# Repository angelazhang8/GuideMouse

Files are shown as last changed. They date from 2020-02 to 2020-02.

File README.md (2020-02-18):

# Guide Mouse
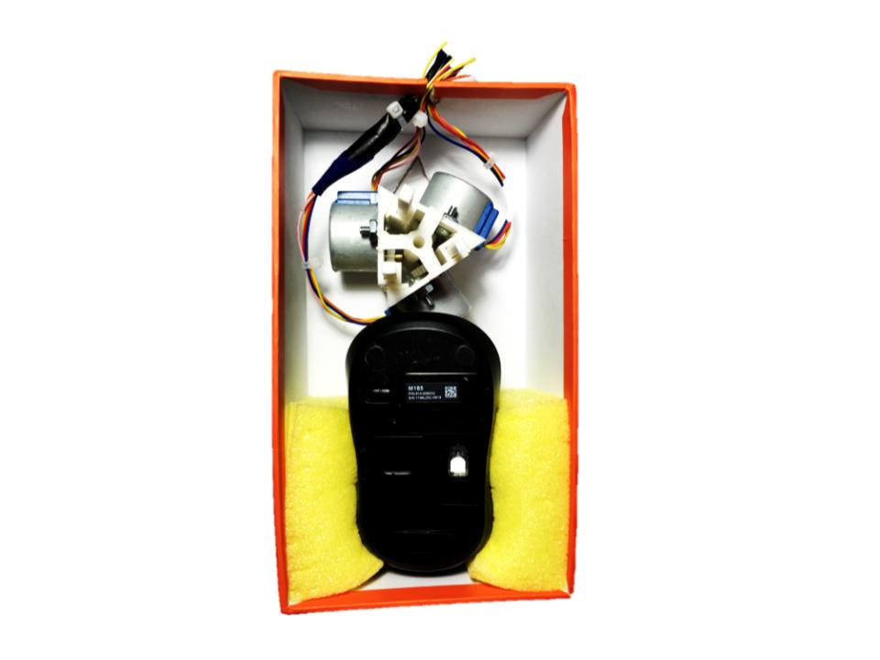
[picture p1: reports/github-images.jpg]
mouse

Guide Mouse allows for the tactile exploration of 3D objects digitally. The program inputs a 3D model while displaying its 2D projection on the screen. Users move the tactile mouse around like a regular computer mouse, which changes the cursor position on the screen. Applicator (the main program running Guide Mouse) identifies the facet of the 3D polyhedron mesh the cursor hovers over on the screen, and it outputs three numerical values to the Arduino board to position a feedback plane by driving three motors that are attached to Guide Mouse.

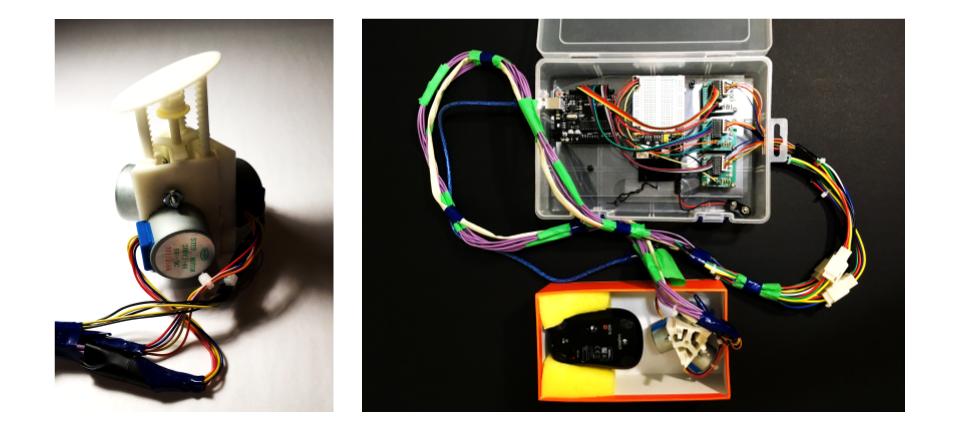
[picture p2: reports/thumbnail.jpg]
thumbnail


## Report & Posters

#### The Applicate Interpolator for a Facet of a 3D Polygon Mesh Given the Abscissa and Ordinate Program

## Program

[Applicolator Report](https://github.com/xxxzhangxxx/GuideMouse/blob/master/reports/applicolatorReport.pdf)

### Poster

[Guide Mouse Poster](https://github.com/xxxzhangxxx/GuideMouse/blob/master/reports/poster.pdf)

## Build Process

[Build Process](https://github.com/xxxzhangxxx/GuideMouse/blob/master/BuildProcess.md)

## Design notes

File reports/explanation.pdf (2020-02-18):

2.
3.

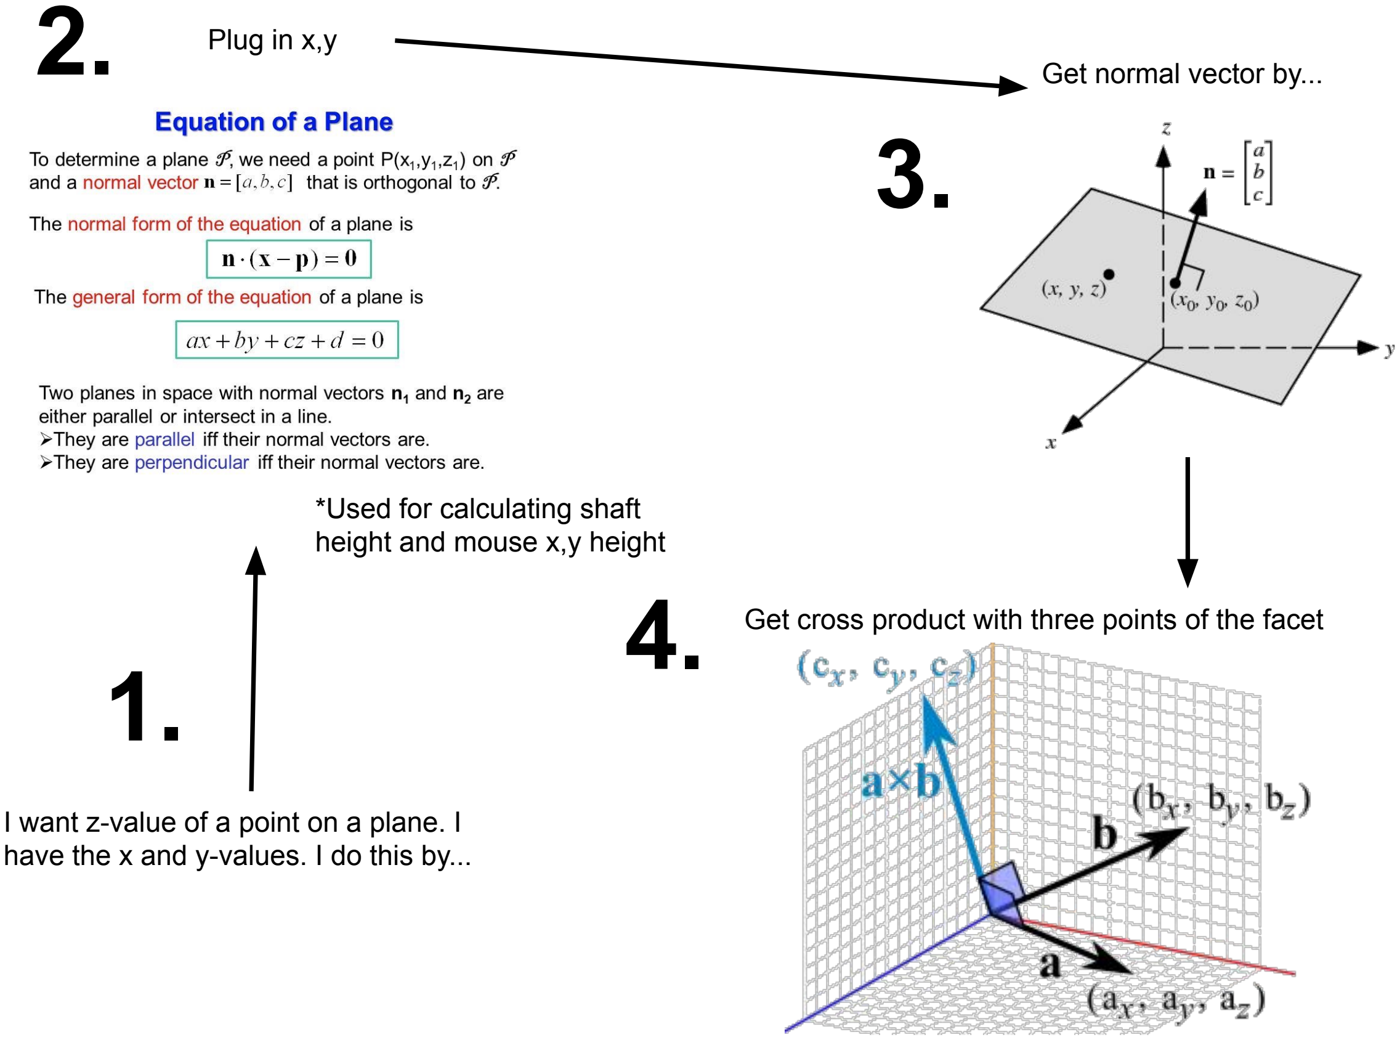
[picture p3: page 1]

Get cross product with three points of the facet

Get normal vector by...

Plug in x,y

I want z-value of a point on a plane. I have the x and y-values. I do this by...

1.

4.

*Used for calculating shaft height and mouse x,y height

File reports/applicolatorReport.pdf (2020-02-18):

# Design Document: Applicolator

# Description of the program

Applicolator displays a 3-dimensional polygon mesh. When the user inputs x,y-values with their cursor position, Applicolator highlights the visible facet that the cursor is currently hovering over and displays its normal vector with a magnitude proportional to the z-value. In order to efficiently locate the visible facet, Applicolator first checks if the x,y-point is in the convex hull of the polyhedron’s projection on the x,y-plane. Second, it builds an interval tree of the smallest enclosing rectangles of facets such that the k facets whose enclosing rectangle the input x,y-values is in can be located in O(k log n) time. Third, for these rectangles, Applicolator uses the ray-casting algorithm to test whether the x,y-values are in the facet. Fourth, Applicolator compares all facets that the x,y-values belong to for the largest z-value. The applicate (z-value) is calculated for the x,y-point by using the normal vector and a point on the facet. The normal vector is calculated by taking the cross product of two vectors obtained from three points on the facet. In this way, the facet that is “on top” can be identified because it will have the greatest z-value. The name Applicolator is derived from The Applicate (z-value) Interpolator for a Facet of a 3-Dimensional Polygon Mesh Given the Abscissa and Ordinate.

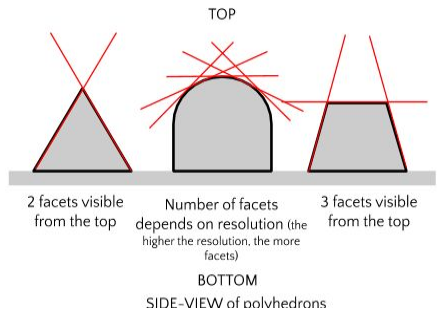
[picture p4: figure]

In computer graphics, one way to define a 3D shape is through a shell/boundary model, which represents the surfaces of the 3D shape like an infinitesimally thin eggshell. Polygon meshes are commonly used, which represents the surfaces of the 3D shape using polygons.

The polygons, also called facets, may be triangles, quadrilaterals, or simple convex polygons. A polygon mesh can be stored in different file formats; Applicolator will be importing .obj files.

A 3D polygon mesh model describes its facets using its own coordinate system, called the object coordinate system. Different .obj files use coordinate systems that represent the length in different units, and the coordinate origin may be far away from the object's center. Applicolator scales and translates the object coordinate system to make the shape fits properly on the computer screen.

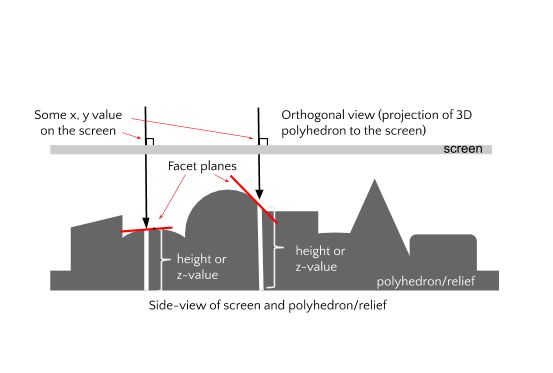
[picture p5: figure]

A polygon mesh will be displayed in an orthogonal view so that x,y-values on the screen match with a scaled version of the polygon mesh. The corresponding applicate (z-value) to the x,y-value can be determined using vector calculations. Applicolator will assume that the z-value is zero at the vertex of the polyhedron containing the smallest z-value and normalize the magnitude of the displayed normal vector to be between zero and one. The ideal polygon mesh for this program is a 3D relief, as reliefs only have one side with 3D detailing.

Essentially, Applicolator is meant to be an interpolator for the z-value given an x,y-value on a plane. In order to achieve this purpose, intermediate calculations are required. These intermediate calculations have, in and of themselves, become useful features.

# Features

Program:
- Identifies and highlights the visible facet that the user’s cursor is hovering over
- Interpolates the z-values, given an x,y-value on the facet
- Display the normal vector of a facet. The magnitude of the vector is first normalized, and then set to the z-value at the x,y-point
- When the user checks off a checkbox, they are able to colour the facets. They can change their colour by turning the colour knobs. In this way, they can create a pretty, coloured 3D shape.

GUI:
- Contain different choices for polyhedrons and reliefs to select from
- Contain different background textures to select from
- Contain an option to check off that allows the user to “colour” the facets for fun
- Contain an RGB colour wheel to allow the user to change the colour of the polyhedron and facets

## Inputs to the program

- An x,y-value that is the cursor’s position on the screen
- GUI inputs
- Checkbox
■ 3D colouring exercise
■ If checked, stop redrawing polyhedron and background
- Dropdowns
■ Texture
■ Polyhedron
- Knobs
■ Change the RGB values for the facet and polyhedron

# Sketch of the User Interface

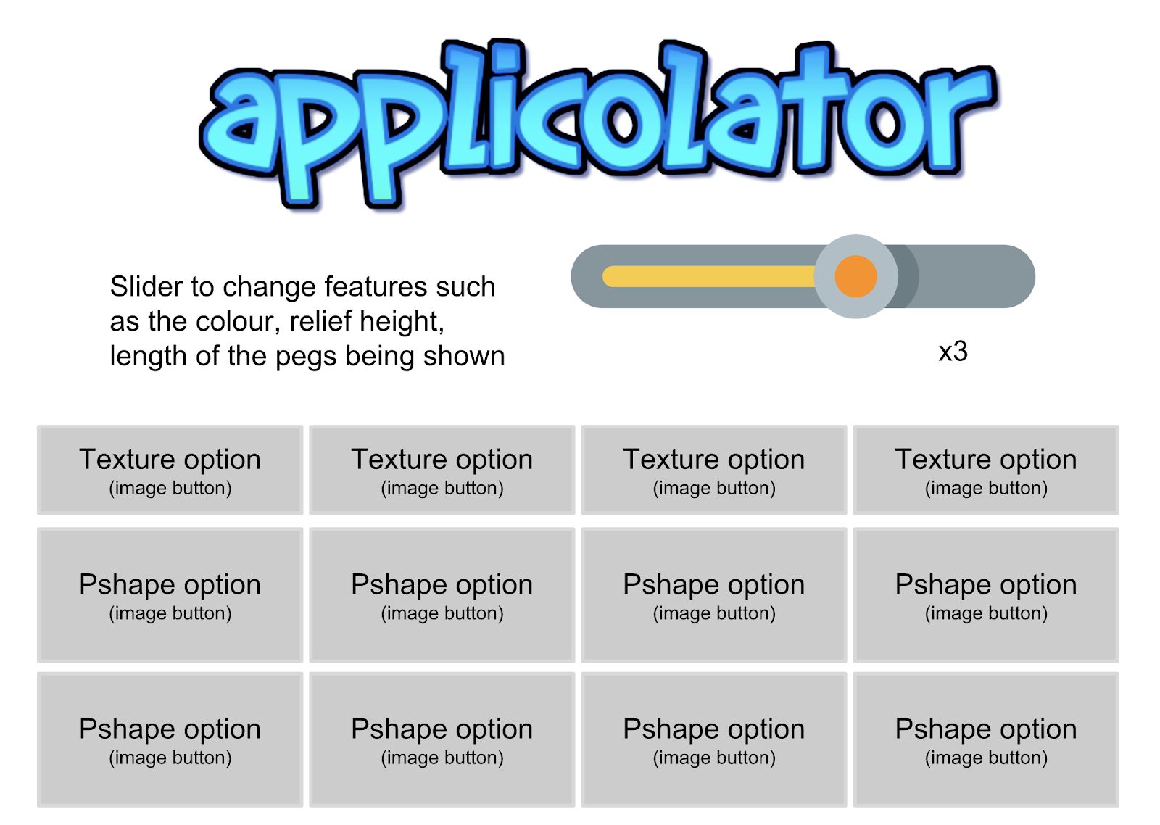
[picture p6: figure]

# Coding structure

## ShapeGeometry2 Class

## General Overview:

Responsible for:
1) Preprocessing the .obj file
- Recursively find all facets, recursively find all vertices
- Finding min/max z-values

2) Storing facets and their smallest enclosing rectangle
- Create an interval tree for the facet’s smallest enclosing rectangle (the top-left-most, top-right-most, bottom-left-most, bottom-right-most points)
- Given an x,y-value, find all the rectangles that it overlaps.

Rules for Interval tree algorithm:
i) The tree is ordered by leftmost x’s value.
ii) | Each node has a maxSubtreeX value which dictates the largest value of x
| in the subtree rooted at that particular node.
iii) | If your point x overlaps with the current node’s shape’s interval, add the
| interval to the result.
iv) | Recur the left child.
v) Recur for the right child if your x value is larger than the right child’s low.
3) Find visible facets
1) Calls convex hull, tests if a point is in the polyhedron’s projection onto the
| x,y-plane
2) Search the interval tree for all the rectangles that enclose the point
3) Test if the point is within the facet using the ray-casting algorithm
4) Calculate the z-value for each point on the facet
5) Compare z-values, the point with the largest z-value is the facet that is
| “on top”
4) Handles vector calculations
- Calculates the normal vector
- Calculate the z-value for an x,y-point

### Fields

PShape convexHull; | Creates shape using points from the convex hull.
float minX, minY, maxX, maxY, maxZ, minZ; | Finds the extreme values from points in convex hull (fewer points to check).
XIntervalTree facetIntervalTree; | Creates an object.

### Methods

ShapeGeometry2() | Empty constructor.
ShapeGeometry2(PShape shape) | Calls the other methods. Initializes fields for the given shape.
void getAllVerticesFromShape(PShape a, HashSet<PVector> v) | Recursive function. Adds all the shape’s vertices to a HashSet to ensure no duplicate values.
private void getAllFacetsFromShape(PShape shape, ArrayList<PShape> allFacets) | Recursive function. Checks if the shape is a facet. If the shape is a facet (the family will have the same constant field value as GEOMETRY), add the facet to the ArrayList. Otherwise, do a recursive call for each child of the shape.

void initializeMinMaxXYZ(HashSet<PVector> vertices) | Initializes field values.
void initializeConvexHull(HashSet <PVector> allVertices) | Creates convex hull from an ArrayList of the polygon’s vertices. Initializes the field value.
float getMinX/getMaxX/getMinY/getMaxY/getMinZ/getMaxZ() / PShape getConvexHull() | Multiple methods that are of the same type. Returns the specified value. Its purpose is to be accessed from other classes.
PShape getVisibleFacet(PVector xy) | First, check if the cursor is within the smallest enclosing rectangle formed by the shape’s four most extreme points. Next, check if the cursor is within the convex hull. Return the final facet with highest z-value or null if the cursor is not on any facet.
boolean isInFacet(PShape shape, PVector xy) | Checks if a point is in a polygon using a ray-casting algorithm https://www.geeksforgeeks.org/how-to-check-if-a-given-point-lies-inside-a-polygon/ (https://www.geeksforgeeks.org/how-to-check-if-a-given-point-lies-inside-a-polygon/)
void setZForXYonPlane(final PVector normal, final PVector position, PVector xy) | Uses vector calculations to find the z-value given the normal vector, position vector and an xy value.
PVector getNormalVector(final PVector a, final PVector b, final PVector c) | Given 3 points on the plane, get the plane’s normal vector.
PVector getNormalVectorAndSetHeight(PShape facet, PVector xy) | Set z-value for cursor position on the screen. Return normal vector. Calls setZForXYonPlane and getNormalVector.

## MotorController Class

## General Overview:

For the future continuation of this project:
- With the eventual goal of making a tactile mouse so that blind people can feel shape geometries of digital objects
- Get the heights for the motors, drives the motors
- Currently, this class does not contribute to the program

### Fields

PVector p1, p2, p3; | Positions of each motor relative to the cursor.
PVector mouseXY; | Where the cursor is.

### Methods

MotorController(PVector p1, PVector p2, PVector p3) | Constructor.
void moveMotor(float h, PVector normal ) | Calls setZForXYonPlane.
void setZForXYonPlane(final PVector normal, PVector xy) | Sets z-values for a motor.
float getMotorHeight(int motor) | Return motor height.

## DirtyWork Class

## General Overview:

- Draw relief, highlight the facet, and draw the normal vector that uses object coordinates on the screen
- Convert the mouseXY position from the screen coordinates to object coordinate
- When the cursor changes position, the process above is repeated and Applicolator then redraws the GUI

### Fields

PShape shape; | Relief or polyhedron.
ShapeGeometry2 sg; | Geometry data of the relief.
float scaleFactor; | Object coordinate to screen coordinate scale multiplier.
MotorController motorController; | Motor data. Not in use in the program
PVector mouseXY; | Current cursor position.
Float normalVectorMagnitudeFactor; | Normal vector magnitude multiplier
float motorHeightFactor | Not in use in the program.

### Methods

void printStates() | Troubleshooting.
void initialize(PShape shape) | Initializes the field scaleFactor. The polyhedron will be scaled on the screen appropriately. Initializes shape geometry.
void mouseMoves() | Call other methods depending on the cursor position.
void drawRelief() | Colours and draws the polyhedron
void highlightFacet(PShape facet) | Colour the facet the cursor is on.
void drawNormalVector(PVector normal, PVector mouseXY) | Draws the normal vector for the facet.
void drawWithObjectCoordinate(PShape shape) | Draw the shape that uses object coordinates on the screen.
void screenToObjectCoordinate(PVector xy) | Change screen space to object space for the cursor.

## Convex Hull Class

General overview:
Implement the Graham Scan algorithm to find the convex hull of a set of vertices.

### Fields (none)

### Methods

ConvexHull() | Empty constructor.
ArrayList<PVector> getConvexHull(HashSet<PVector> v) | Return the convex hull of the provided set of vertices, which must be distinct in terms of x and y.
int indexOfBottomestPoint(ArrayList<PVector> points) | Returns the index of the point with the smallest 'y' value
swap(ArrayList<PVector> points, int i, int j) | Swap the points at the two indexes in the array
float counterClockWise (PVector o, PVector a, PVector b) | Position vectors 'a' and 'b' Calculate the cross product of vectors 'a' and 'b' If ccw > 0, then counterclockwise, or < 180 degrees If ccw < 0, then clockwise, or > 180 degrees If ccw = 0, then collinear
float calculateDistance(PVector a, PVector b) | Return the distance between the two points.
ArrayList<PVector> grahamScan(ArrayList<PVector> points) | Graham Scan algorithm: https://en.wikipedia.org/wiki/Graham_scan

| Take in an array of points sorted by polar angles The point at index 0 is the origin Returns the convex hull, the points are in the same order as in the input array
ArrayList<PVector> sortByPolarAngle(ArrayList<PVector> points) | Take the ArrayList 'points' and sort them based on: 1. The point at index 0 is the origin 2. Find position vectors for all points using the newly established origin 3. Sort points based on their vectors' polar angles
ArrayList<PVector> mergeSort(PVector o, ArrayList<PVector> v, int start, int end) | Sorts the vectors in the specified range by polar angle. The vectors are from the point 'o' to the points in the ArrayList v. Both start and end are inclusive.
ArrayList<PVector> merge(PVector o, ArrayList<PVector> a, ArrayList<PVector> b ) | Merge the two arrayLists.

## XIntervalTree Class

General overview:
Interval tree of rectangles. The key is the x1 of the rectangles. The interval refers to [x1, x2]. A node may contain multiple shapes with the same x1; these shapes are stored in the list swer. The k number of smallest-enclosing rectangles that a point (x,y-value from the cursor) is within can be found in O(k log n) time where n is the number of nodes.

### Fields

XIntervalTreeNode root; | Root of the interval tree.
int numNodes, numRectangles; | The number of nodes in tree and number of enclosing rectangles. For debugging purposes

### Methods

ArrayList<PVector> getConvexHull(HashSet<PVector> v) | Return the convex hull of the provided set of vertices, which must be distinct in terms of x and y.
XIntervalTreeNode buildTree(ArrayList<ShapeWithEnclosingRectangle> swer, int begin, int end) | Build the interval tree using the elements of swer in the range of begin to end. Begin is inclusive, end is exclusive. Swer has been sorted by x1. Recursively build the tree. Get the middle node every level. If you left and right and the values for x1 are the same, add it to the current node. Recursively build left and right side of the tree. Update maxsSubtreeX.
ArrayList<ShapeWithEnclosingRectangle> getAllRectanglesOverlapXY(float x, float y) | Return all rectangles that overlap with the provided x and y values.
void getAllRectanglesOverlapXY(XIntervalTreeNode node, float x, float y, ArrayList<ShapeWithEnclosingRectangle> result) | Add rectangles that overlap with the provided x and y to results. Recursively gets called for each side of the tree.
void printTree(boolean verbose) | For testing purposes.
void printTree(String indent, XIntervalTreeNode root,
boolean verbose)

## ShapeWithEnclosingRectangle Class

### Fields

PShape shape; | Facet in question.
float x1, x2, y1, y2; | Coordinates of the smallest enclosing rectangle

### Methods

ShapeWithEnclosingRectangle(PShape shape) | Constructor.
boolean overlapX(float x) | Whether the given x is within x-range of the smallest enclosing rectangle
boolean overlapY(float y) | Whether the given y is within y-range of the smallest enclosing rectangle
public int compareTo(ShapeWithEnclosingRectangle other) | Used by Collections.sort to sort objects of this class by x1
void printStates() | For troubleshooting.

## XIntervalTreeNode Class

General Overview:
A node on the interval tree. The key is the x1 of the rectangle. The interval refers to [x1, x2]. A node may contain multiple shapes with the same x1; these shapes are stored in the list swer.

### Fields

XIntervalTreeNode left, right; | Left and right child node of the current node.
ArrayList<ShapeWithEnclosingRect angle> swer; | All enclosing rectangles with the same x1.
float maxSubtreeX; | Max value of x2 in all nodes under the current node.
float x1; | The leftmost x-value, same for all enclosing rectangles

### Methods

XIntervalTreeNode(ShapeWithEnclosingRectangle r) | Constructor.
void add(ShapeWithEnclosingRectangle r) | Add the rectangle of the same x1 to the node.
void printStates() | Troubleshooting purposes.

# Restrictions and Requirements

The requirement for the ideal 3D polyhedron for Applicolator:
- From a top view, all facets of interest must be visible
- .obj files for polygon meshes cannot exceed the size that Processing allows with minimal lagging
- If file sizes are too large, reduce file size by reducing the number of facets in the polygon mesh using a tool such as Blender

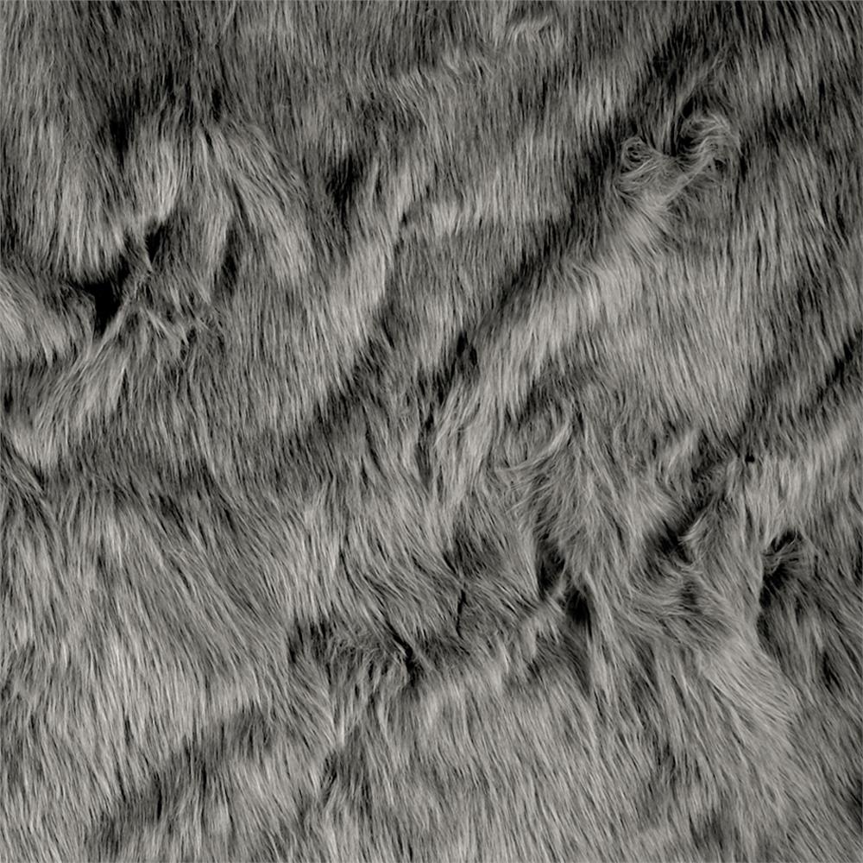
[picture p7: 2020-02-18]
Processing-code/t-fur.jpg

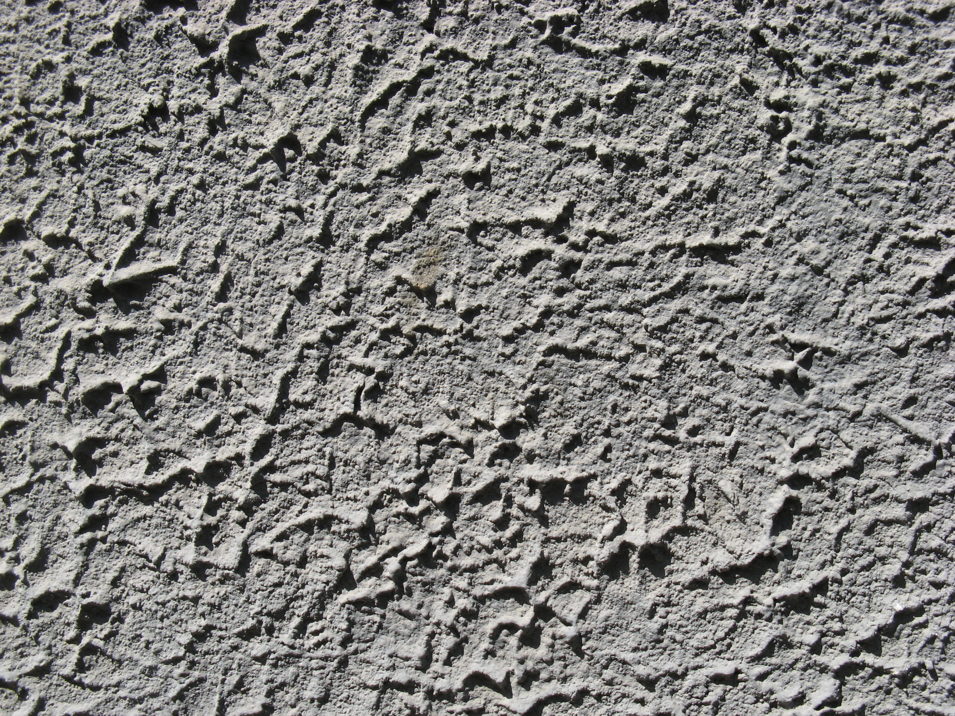
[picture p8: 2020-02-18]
Processing-code/t-plaster.jpg

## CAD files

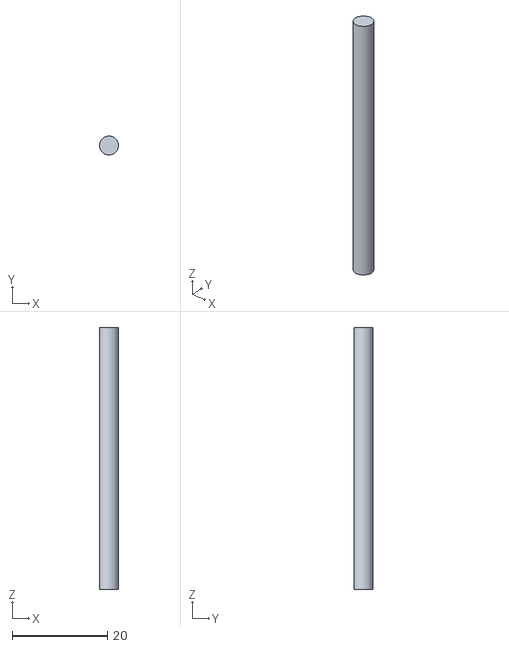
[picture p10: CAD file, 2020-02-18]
AutoCAD-models/STL files/middle-peg.stl
4.00 x 4.00 x 55.0

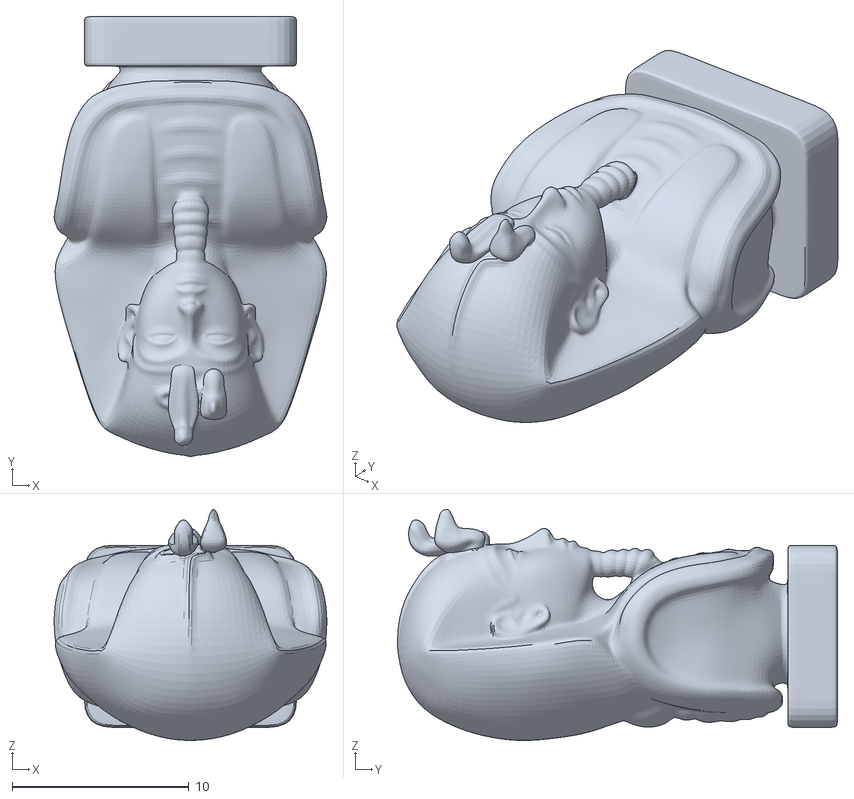
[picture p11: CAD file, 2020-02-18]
Processing-code/s-pharaoh.obj
15.4 x 24.9 x 13.1

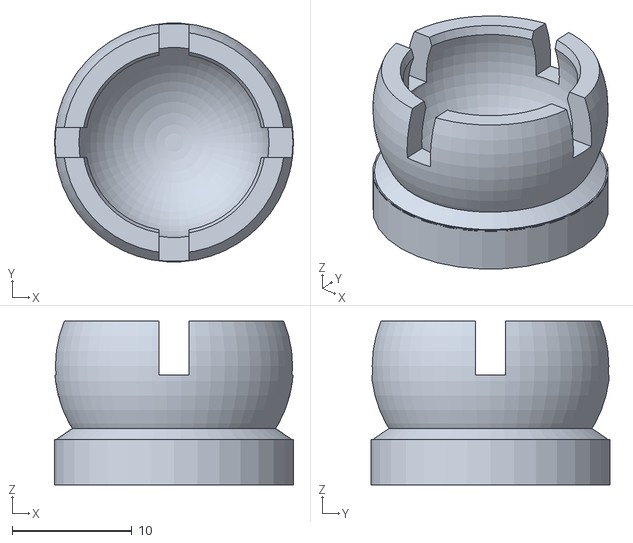
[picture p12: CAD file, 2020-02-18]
AutoCAD-models/STL files/socket_(resize-to-0.51-to-3D-print).stl
20.0 x 20.0 x 13.7

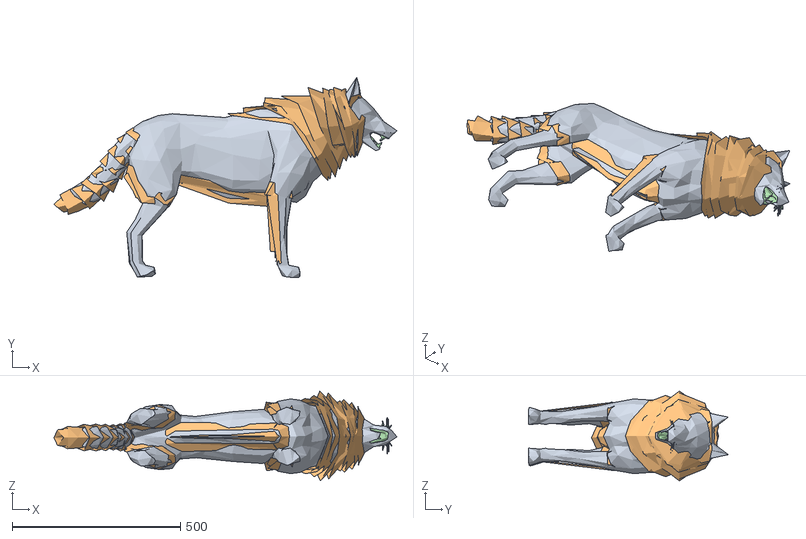
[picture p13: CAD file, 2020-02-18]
Processing-code/s-wolf.obj
1018.1 x 593.0 x 266.8
grp1
grp1 grp1_2
grp1 grp3
grp1 grp2

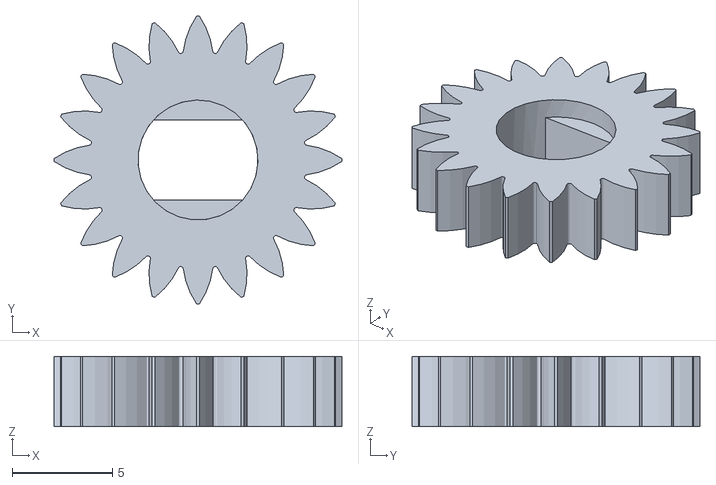
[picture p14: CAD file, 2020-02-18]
AutoCAD-models/STL files/gear.stl
14.4 x 14.4 x 3.50

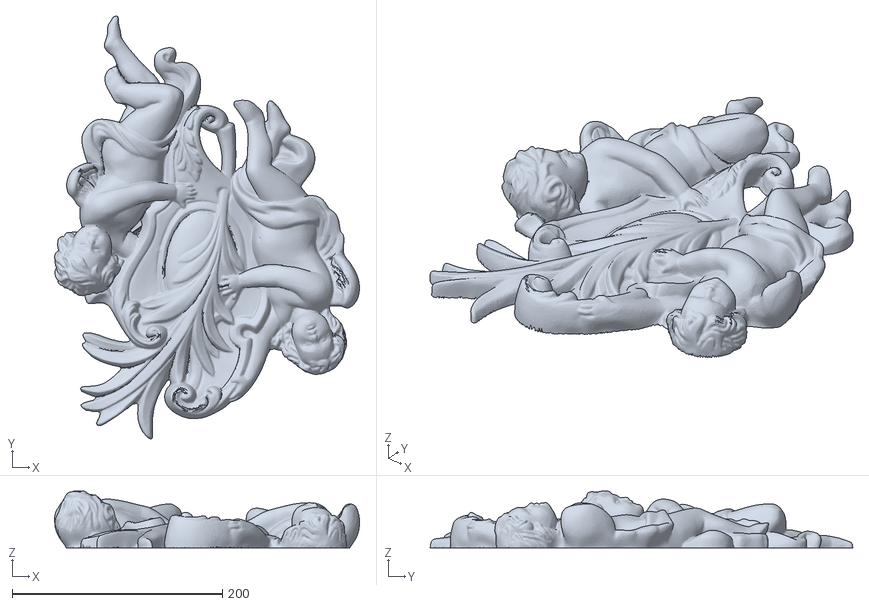
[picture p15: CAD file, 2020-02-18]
Processing-code/s-relief-angel.obj
290.4 x 402.7 x 54.2

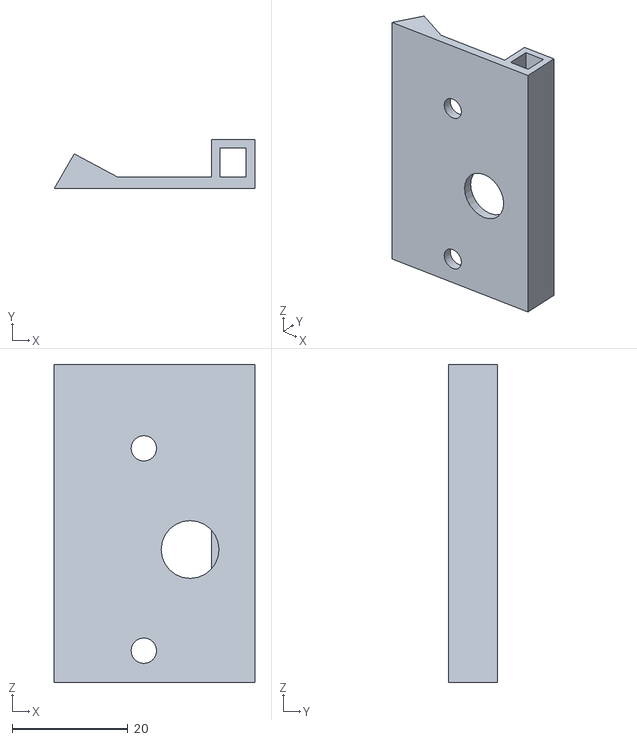
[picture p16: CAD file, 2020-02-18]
AutoCAD-models/STL files/motor-holder.stl
34.7 x 8.50 x 55.0

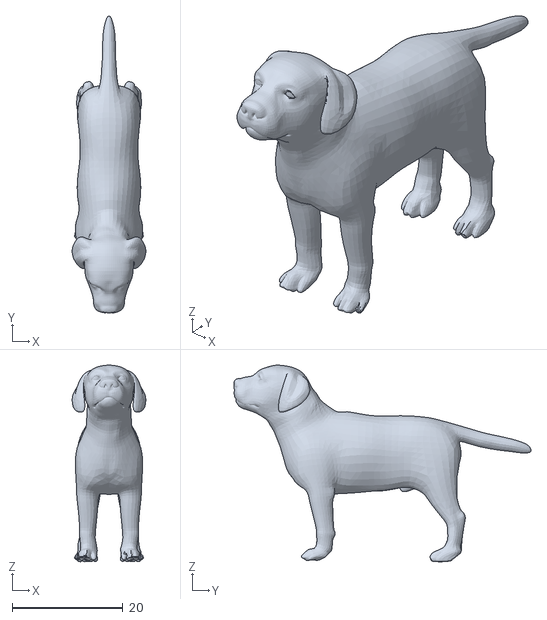
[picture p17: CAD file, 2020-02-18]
Processing-code/s-dog.obj
13.3 x 53.6 x 35.5

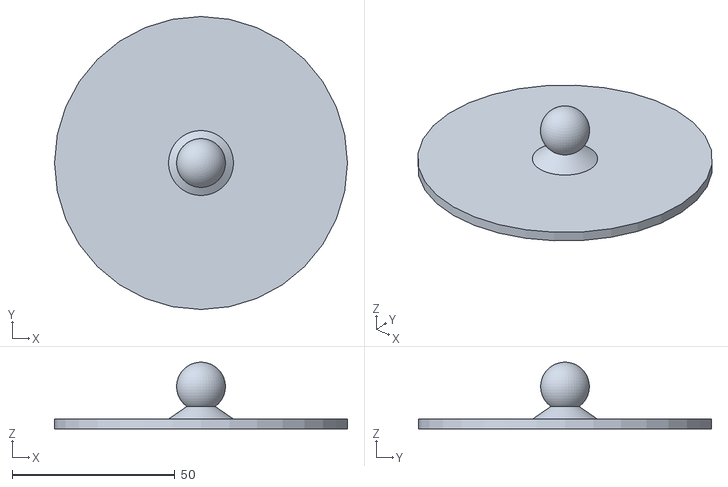
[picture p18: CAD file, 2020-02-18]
AutoCAD-models/STL files/disk_(resize-0.5-to-3D-print).stl
90.0 x 90.0 x 20.5

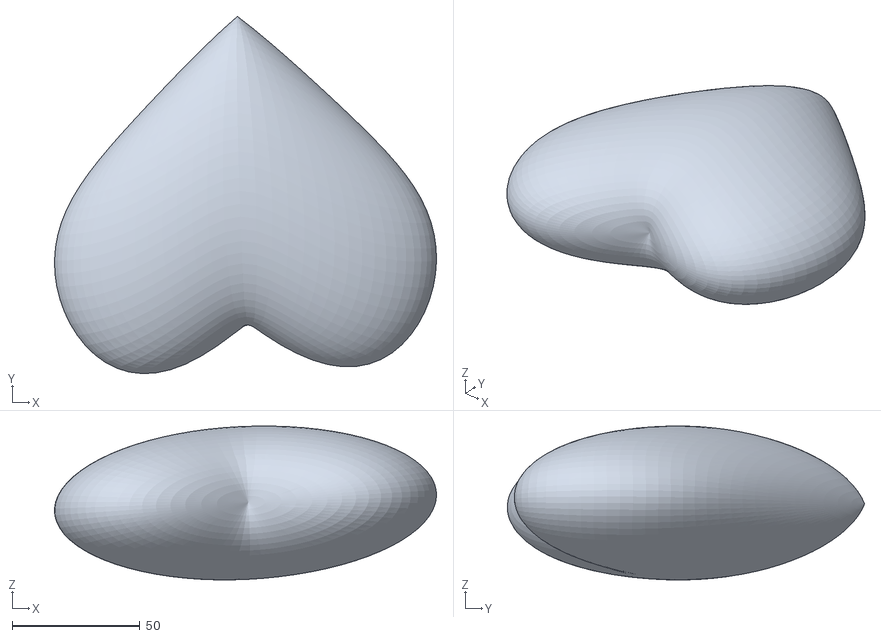
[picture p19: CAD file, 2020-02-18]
Processing-code/s-heart.obj
149.8 x 140.1 x 60.3

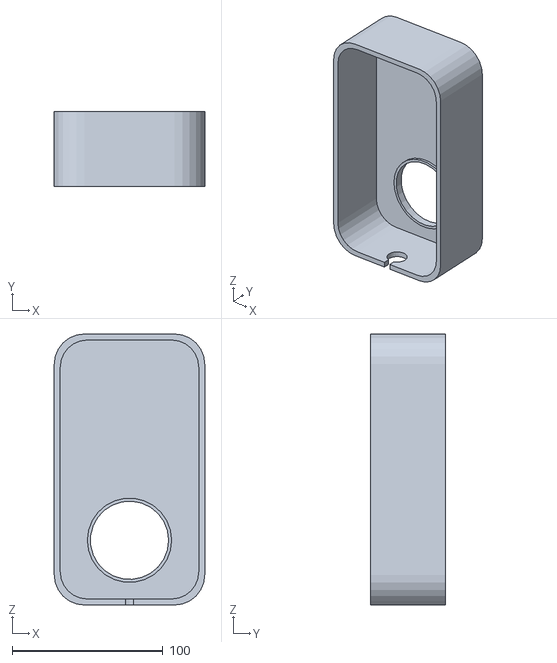
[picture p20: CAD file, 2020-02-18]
AutoCAD-models/STL files/mouse-shell.stl
100.0 x 50.0 x 180.0

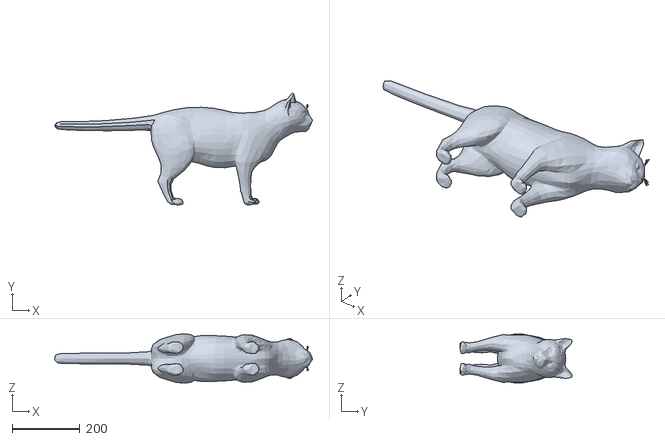
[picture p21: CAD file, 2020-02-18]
Processing-code/s-cat.obj
762.0 x 331.2 x 144.4

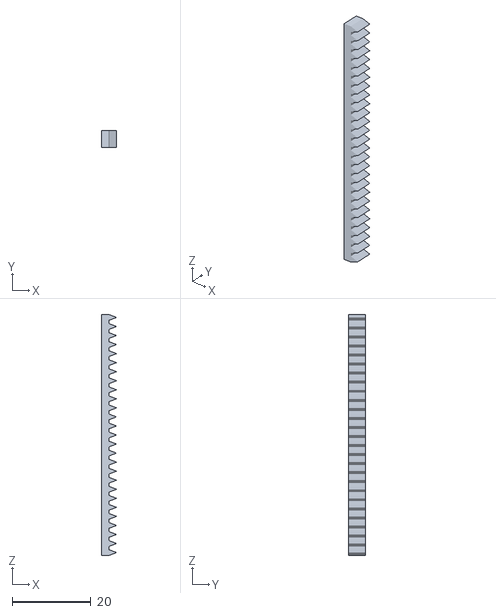
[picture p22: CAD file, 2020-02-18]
AutoCAD-models/STL files/rack.stl
3.88 x 4.40 x 61.3

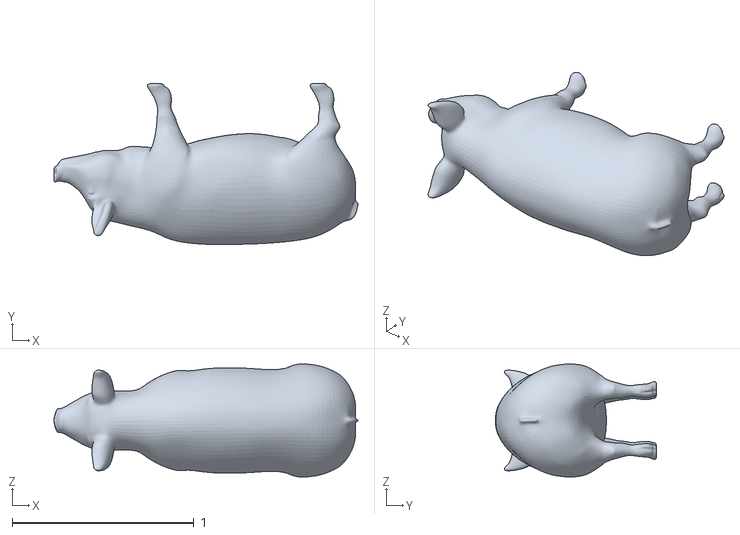
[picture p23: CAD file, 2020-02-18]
Processing-code/s-pig.obj
1.67 x 0.886 x 0.621

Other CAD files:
AutoCAD-models/DWG files/moto-holder.dwg
AutoCAD-models/STL files/middle-peg-holder.stl
Processing-code/s-rat.obj
Processing-code/s-tree.obj
AutoCAD-models/DWG files/disk.blend
AutoCAD-models/DWG files/gear.dwg
AutoCAD-models/DWG files/middlepeg.dwg
AutoCAD-models/DWG files/mouse-shell.dwg
AutoCAD-models/DWG files/rack.dwg
AutoCAD-models/DWG files/socket.blend
Processing-code/s-angel.obj
Processing-code/s-cow.obj
Processing-code/s-deer.obj
Processing-code/s-goat.obj

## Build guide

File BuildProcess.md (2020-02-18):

### Inspiration 
I was inspired to create Guide Mouse after trying out the Phantom Omni at SHAD Western '17. 
Computers have auditory feedback (speakers) and visual feedback (screen) but no tactile feedback. Touch feedback is a large component of our day-to-day lives, yet a nonexistment form of interaction with our desktop computers. I wanted to build this project because Guide Mouse is a product I would like to use.

### Ideation
Going into this project, I had no idea what Guide Mouse was going to look like. So I made rough sketches and then migrated to making paper and foam models to flesh out my idea.

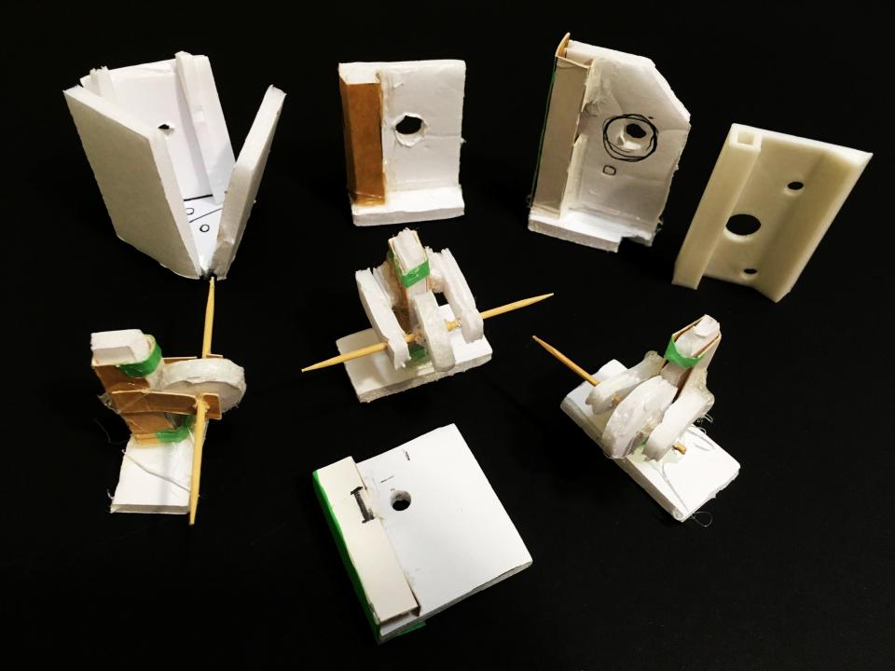
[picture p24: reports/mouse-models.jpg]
mouse-models


### Applicolator
To obtain the normal vector for each facet plane of the polyhedron mesh, I calculated the cross product of two vectors making up the facet plane.
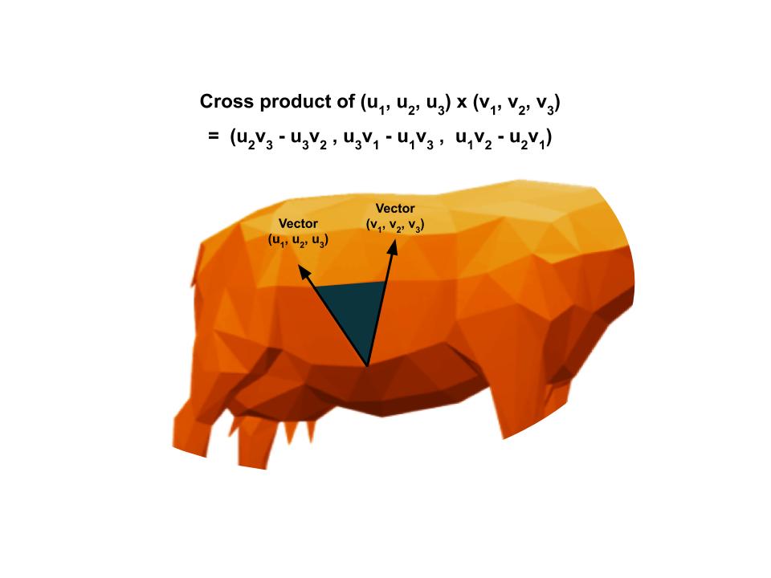
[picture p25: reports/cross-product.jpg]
cross-product

### CAD Modelling
After Guide Mouse had become a skeleton of an idea, I proceded to make CAD models for the parts I needed to 3D-print. Ball/socket model [not pictured] was mixed in Blender from Ball/Joint in Thingiverse.

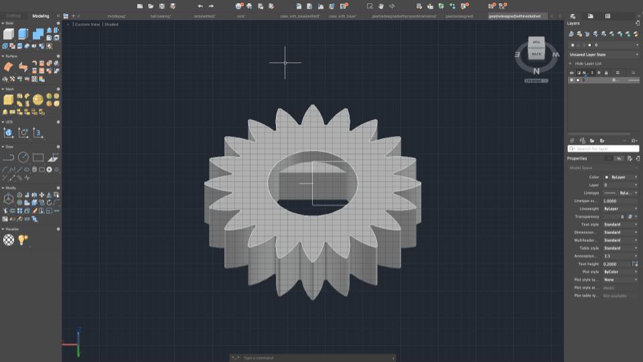
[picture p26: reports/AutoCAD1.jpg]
AutoCAD1

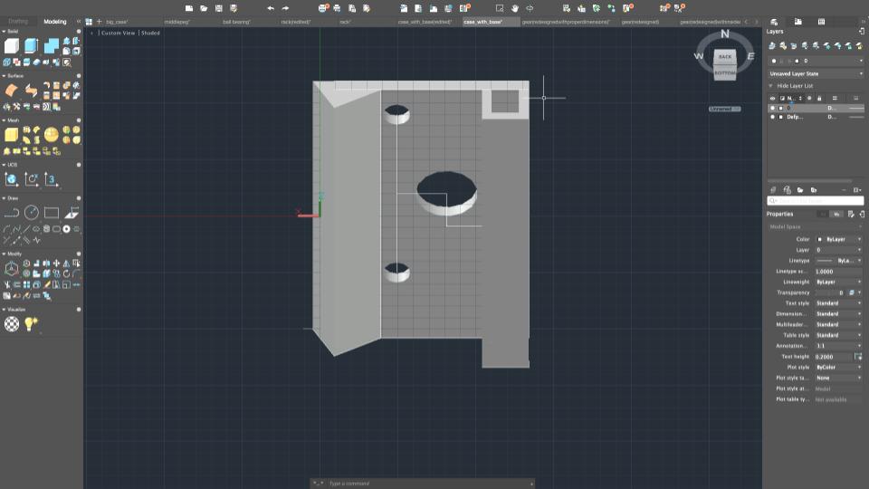
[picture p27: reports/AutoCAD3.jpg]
AutoCAD3

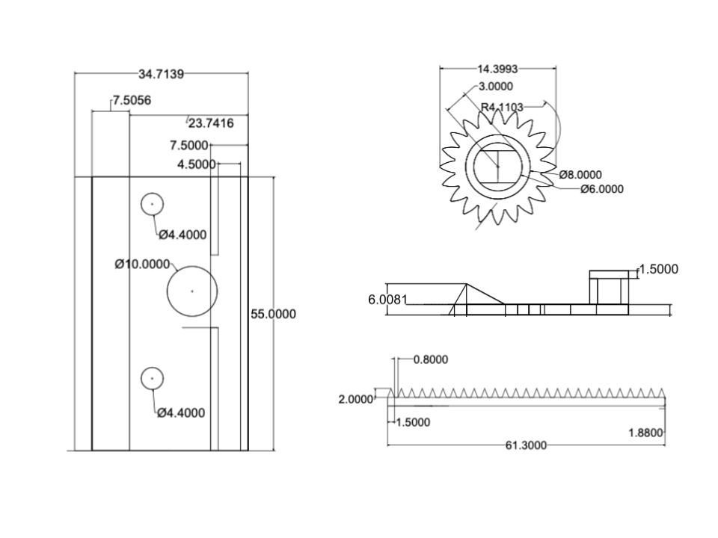
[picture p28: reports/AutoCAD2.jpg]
AutoCAD2

### 3D-Printing
My high school had the Cubicon 3D printer which I used to print my parts.

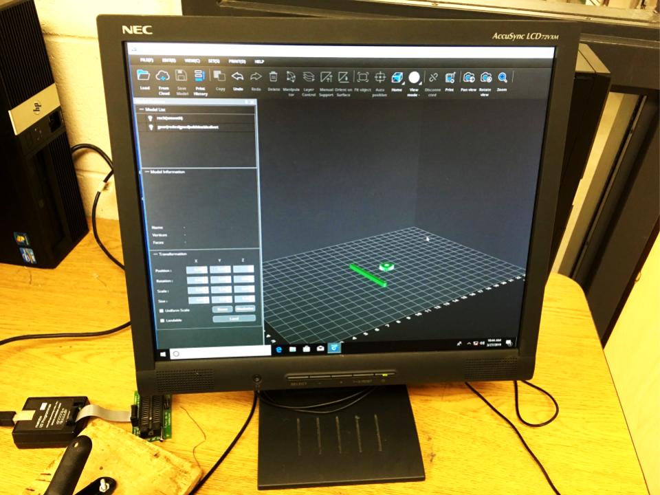
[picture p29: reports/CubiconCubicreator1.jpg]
CubiconCubicreator1

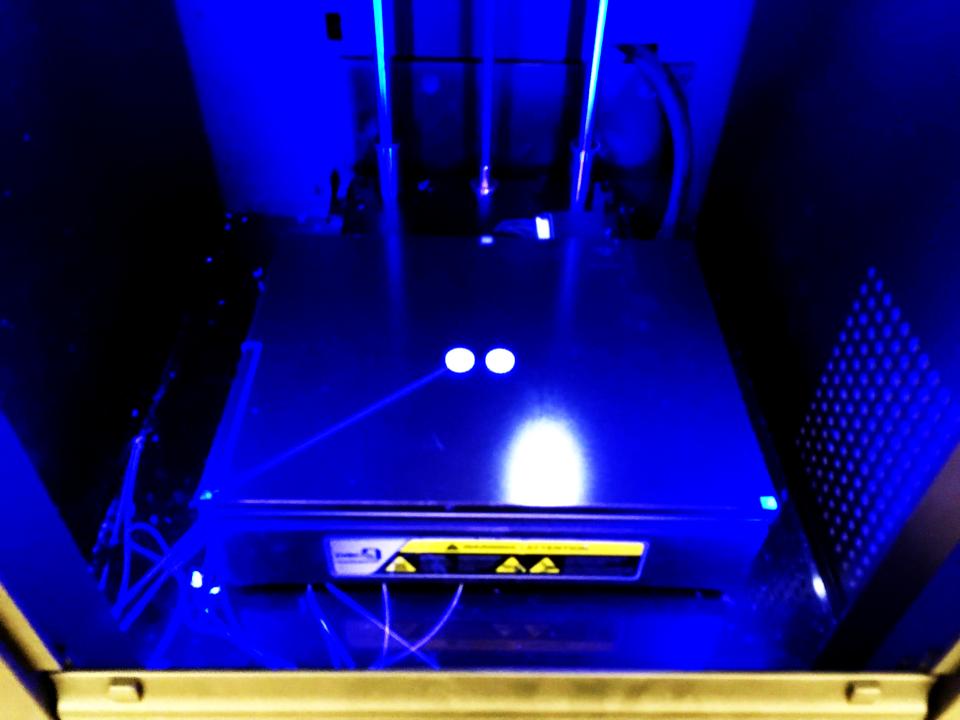
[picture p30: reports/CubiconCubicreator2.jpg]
CubiconCubicreator2


### Soldering (16 hours)
My impromptu work station in the basement; my setup was a ping pong table covered with a picnic blanket. I soldered a computer connector from the motor chip to the motors so that the motors have longer connecting wires and can be easily separated from the motor chip.

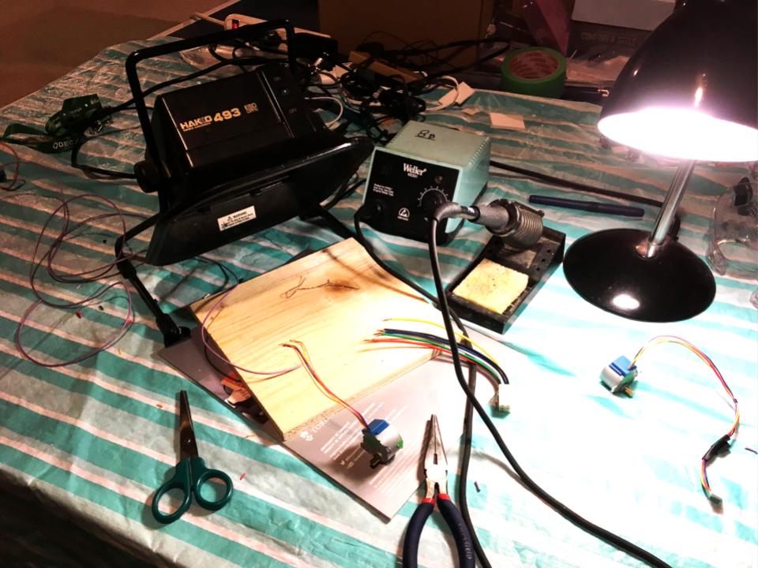
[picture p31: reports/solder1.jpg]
solder1

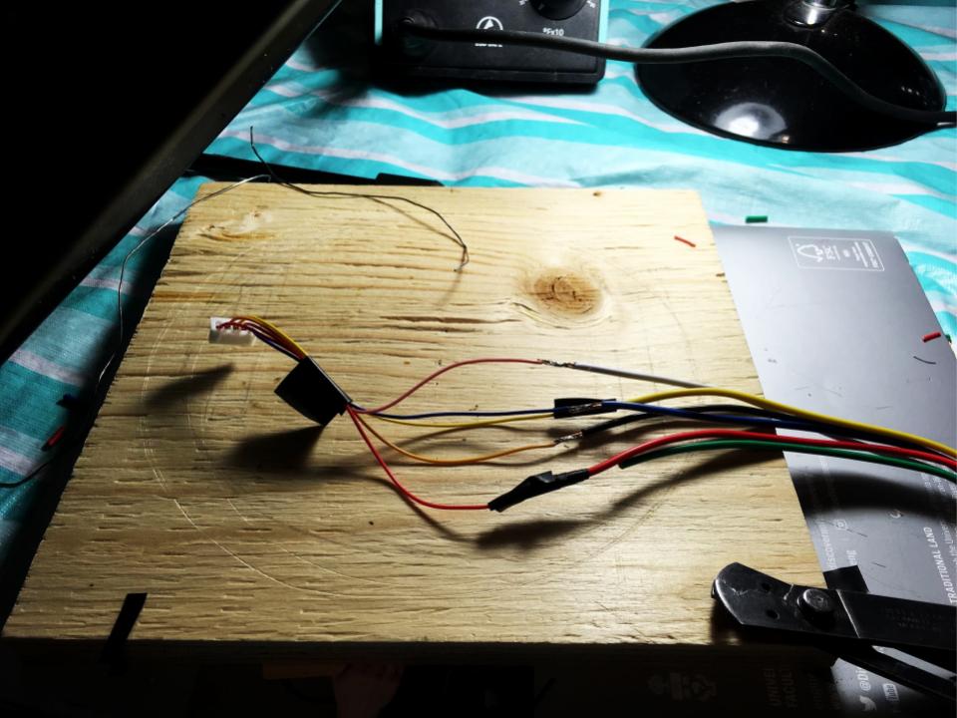
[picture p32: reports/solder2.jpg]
solder2


Wires were stripped, twisted, soldered, and taped. Soldering iron, fan, pliers/cutters were generously lent by Mr. Webb.

### Putting it together
After months of work, it's finally time to fit all the pieces together!

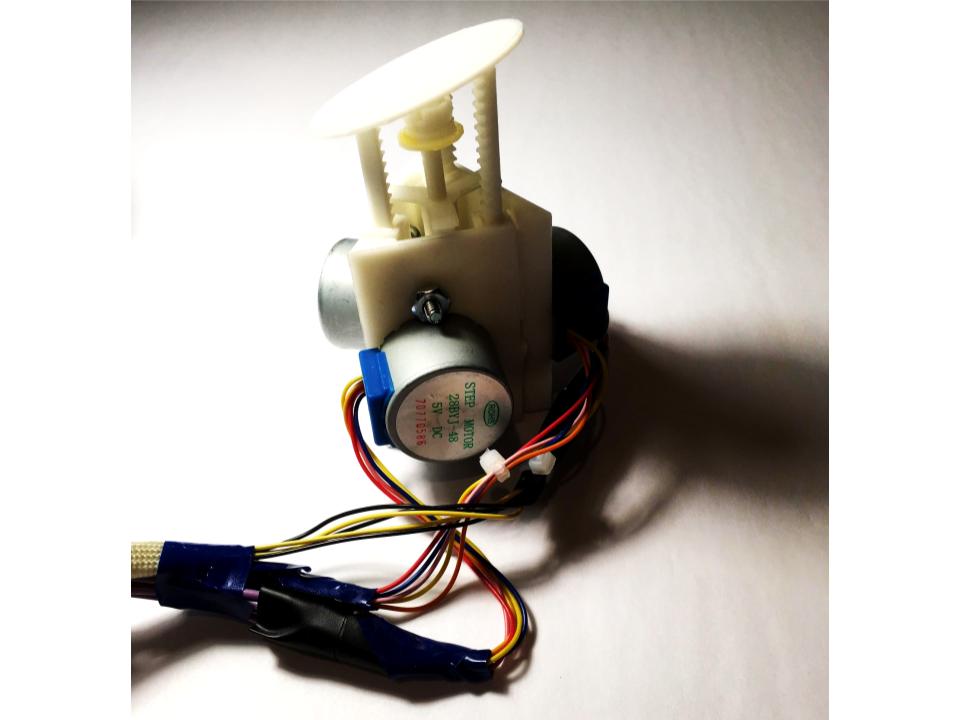
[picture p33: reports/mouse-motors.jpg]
mouse-motors

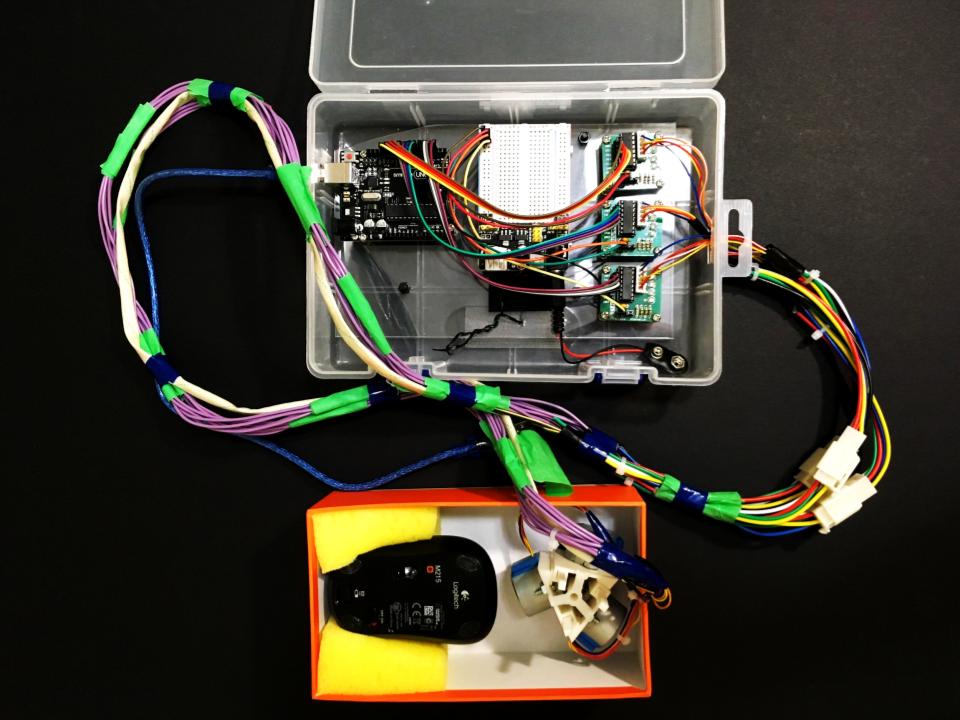
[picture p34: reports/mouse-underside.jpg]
mouse-underside


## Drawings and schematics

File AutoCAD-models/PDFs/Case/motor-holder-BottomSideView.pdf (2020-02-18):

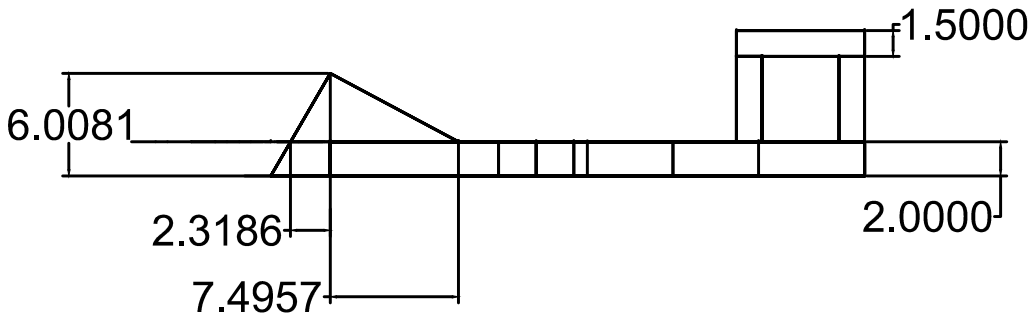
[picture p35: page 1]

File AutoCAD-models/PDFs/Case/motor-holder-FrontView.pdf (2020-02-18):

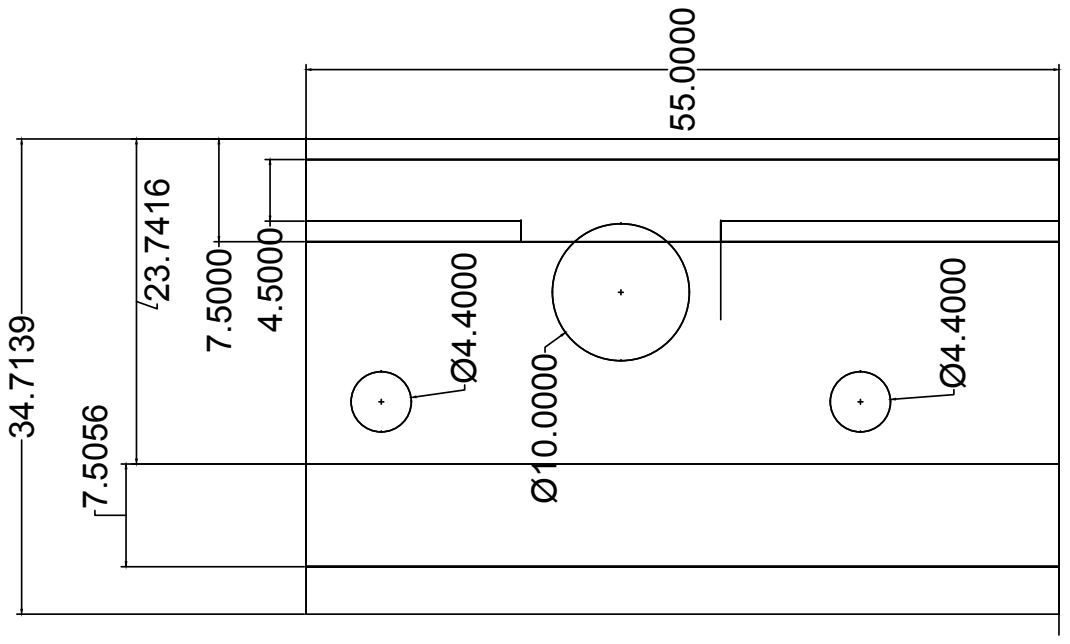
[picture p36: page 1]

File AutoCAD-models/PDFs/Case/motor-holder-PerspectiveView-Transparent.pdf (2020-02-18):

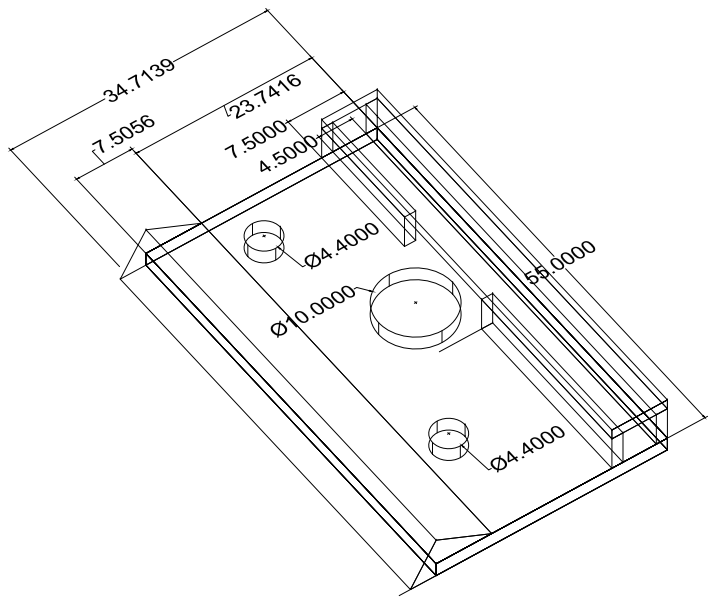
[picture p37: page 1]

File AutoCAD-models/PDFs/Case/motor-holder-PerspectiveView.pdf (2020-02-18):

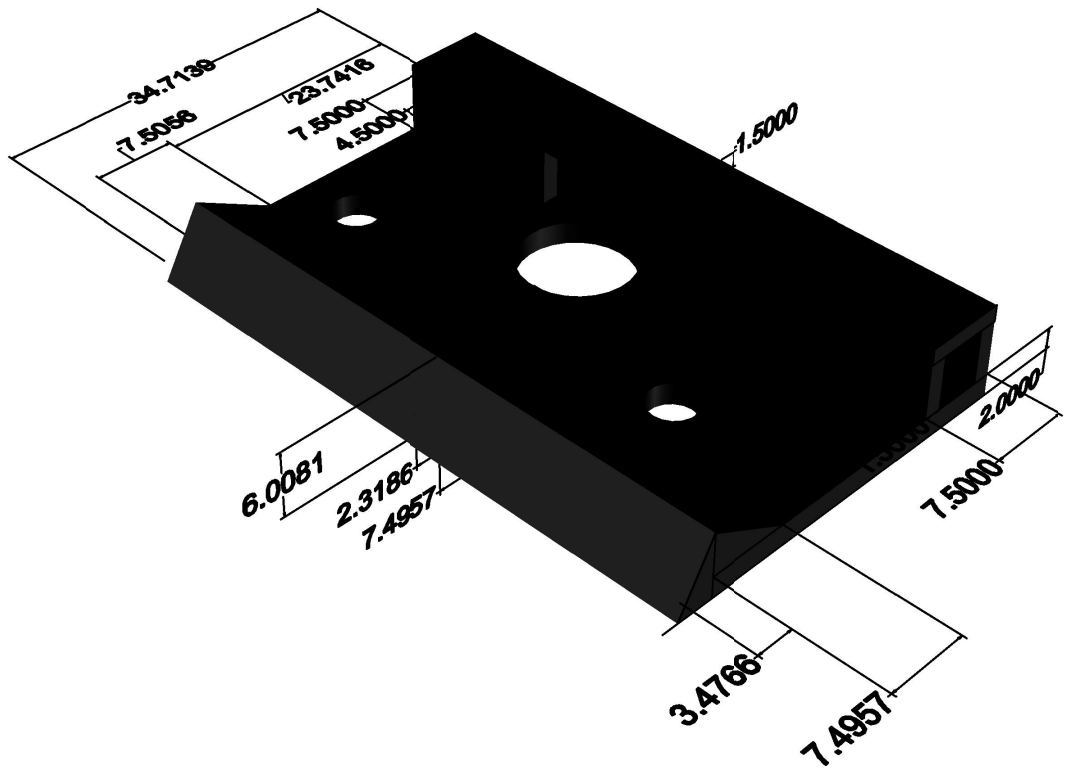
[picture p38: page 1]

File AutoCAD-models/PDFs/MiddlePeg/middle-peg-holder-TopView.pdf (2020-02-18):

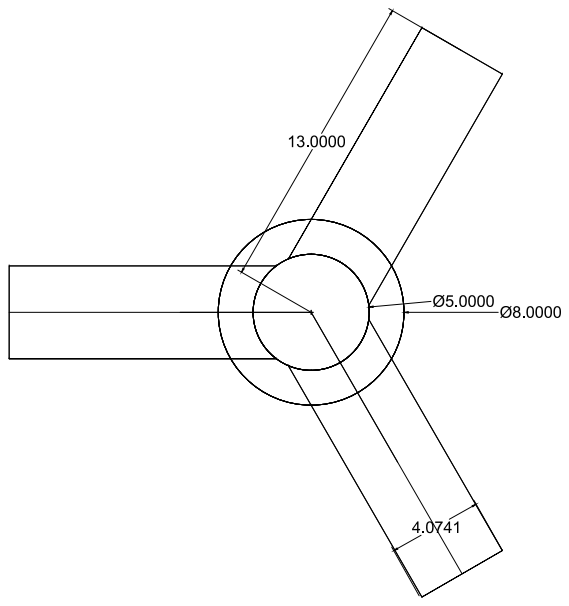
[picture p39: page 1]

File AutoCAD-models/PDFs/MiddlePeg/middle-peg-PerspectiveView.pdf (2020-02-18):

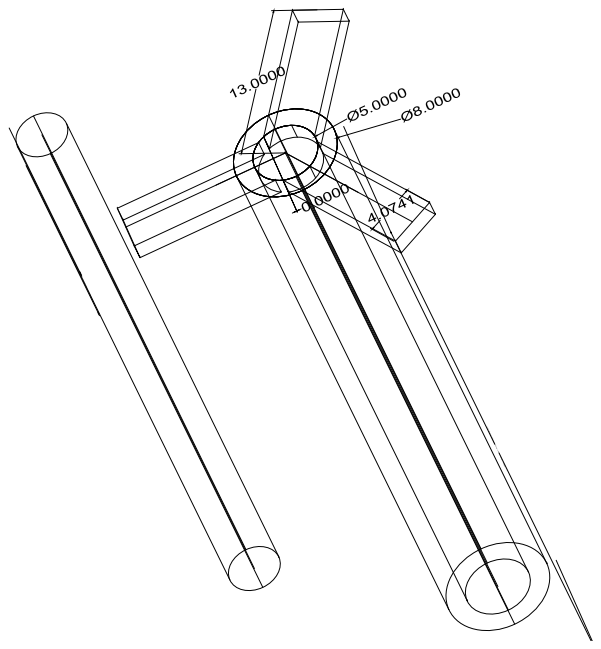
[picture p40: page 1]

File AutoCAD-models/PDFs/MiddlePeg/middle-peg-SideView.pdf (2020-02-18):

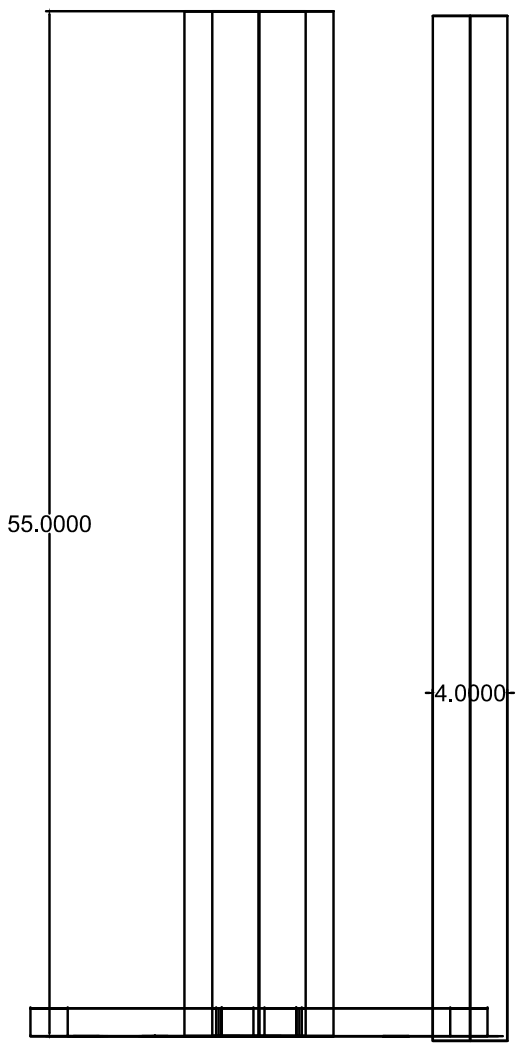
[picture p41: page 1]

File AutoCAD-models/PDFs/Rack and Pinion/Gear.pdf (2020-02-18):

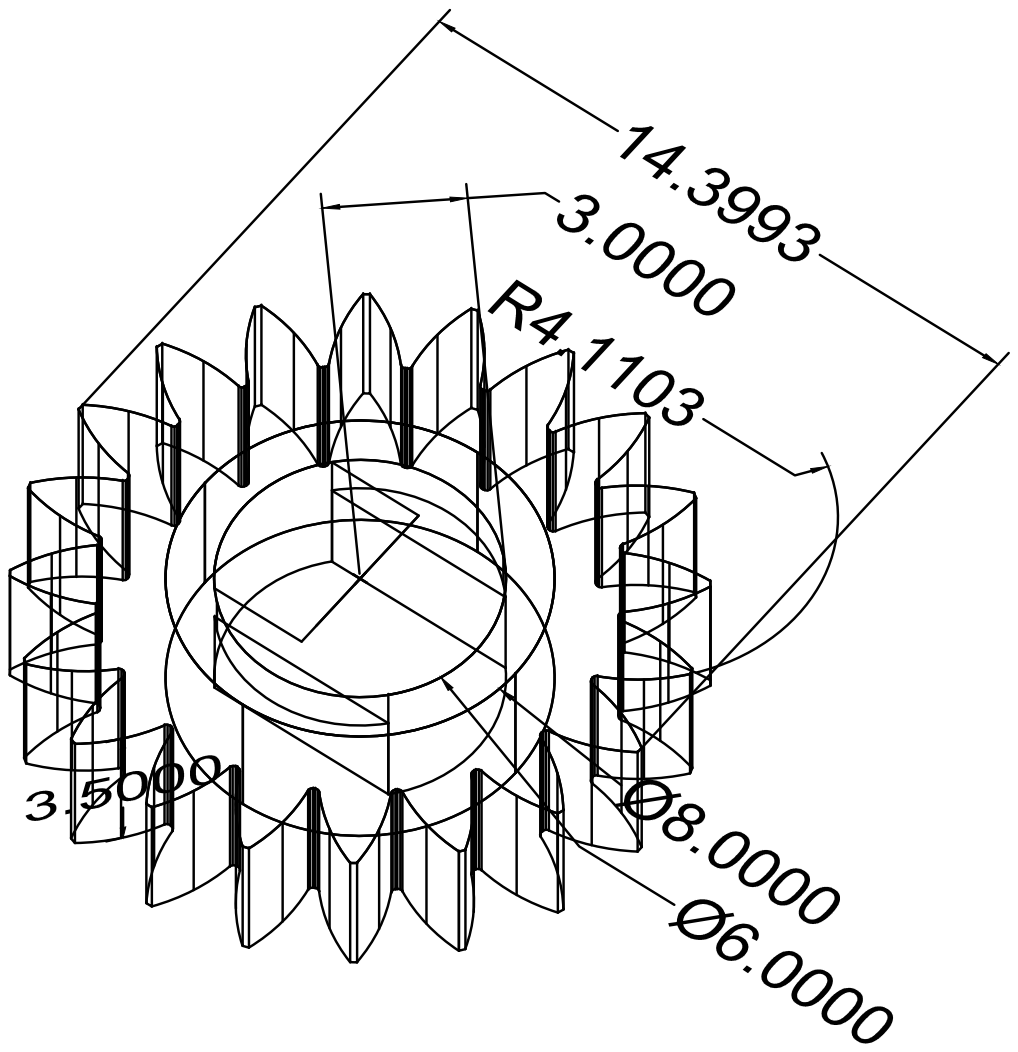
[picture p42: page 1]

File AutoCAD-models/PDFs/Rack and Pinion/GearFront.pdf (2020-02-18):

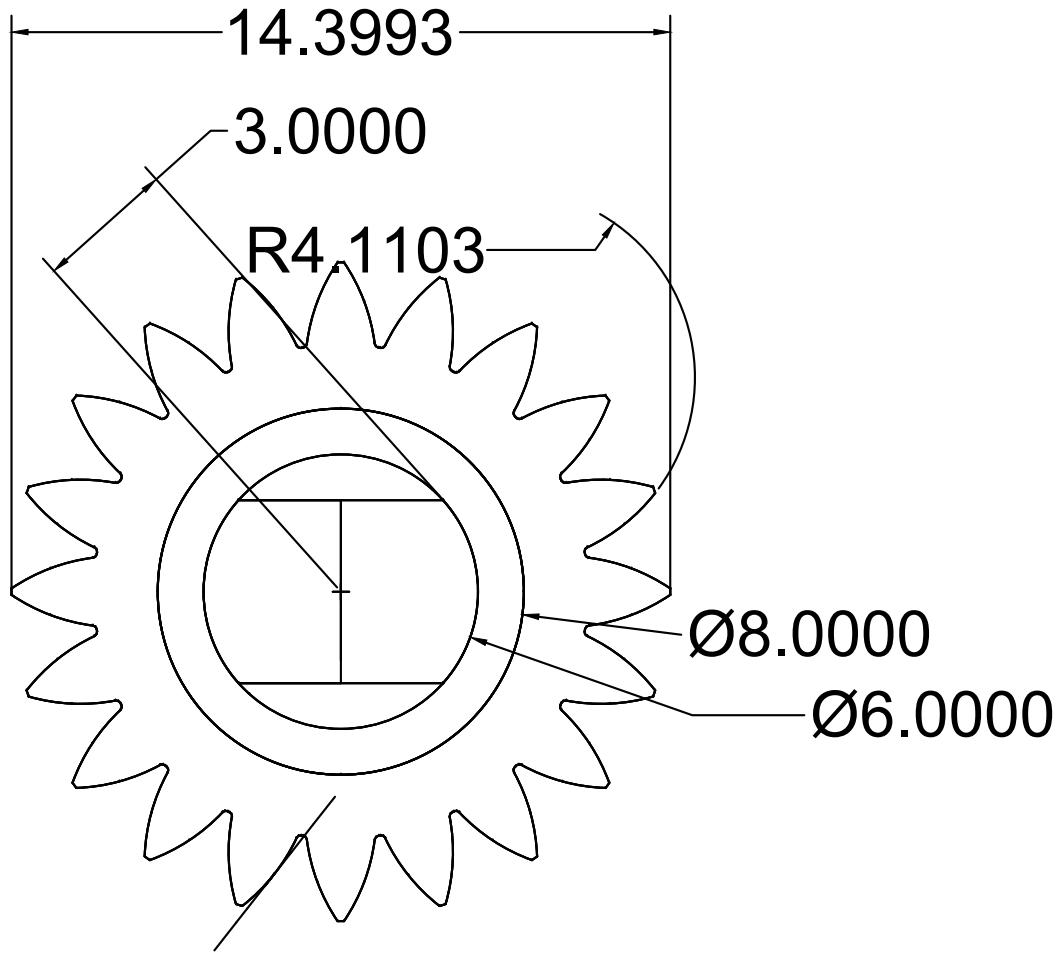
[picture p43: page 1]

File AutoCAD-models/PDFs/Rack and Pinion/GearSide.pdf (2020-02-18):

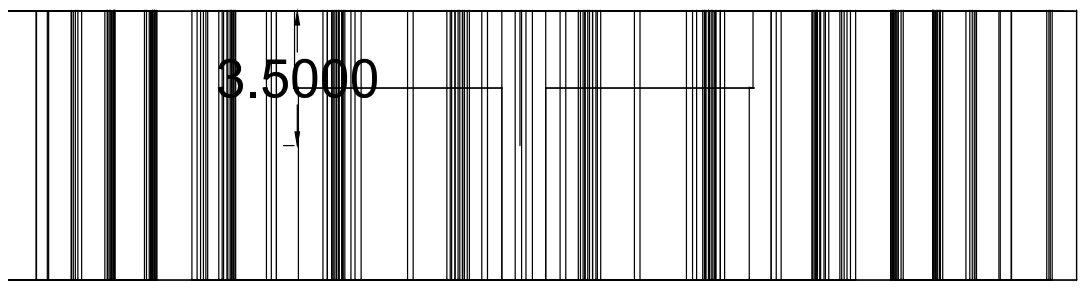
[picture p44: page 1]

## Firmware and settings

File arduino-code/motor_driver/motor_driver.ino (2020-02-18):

#include <AccelStepper.h>

// https://www.instructables.com/id/BYJ48-Stepper-Motor/
#define  STEPS_PER_REVOLUTION = 4096;

// https://www.airspayce.com/mikem/arduino/AccelStepper/classAccelStepper.html
#define HALF4WIRE 8

// motor pins
#define motorPin1  2      // IN1 on the ULN2003 driver 1
#define motorPin2  3      // IN2 on the ULN2003 driver 1
#define motorPin3  4      // IN3 on the ULN2003 driver 1
#define motorPin4  5      // IN4 on the ULN2003 driver 1

#define motorPin5  6      // IN1 on the ULN2003 driver 2
#define motorPin6  7      // IN2 on the ULN2003 driver 2
#define motorPin7  8      // IN3 on the ULN2003 driver 2
#define motorPin8  9      // IN4 on the ULN2003 driver 2

#define motorPin9  10     // IN1 on the ULN2003 driver 3
#define motorPin10  11    // IN2 on the ULN2003 driver 3
#define motorPin11  12    // IN3 on the ULN2003 driver 3
#define motorPin12  13    // IN4 on the ULN2003 driver 3

AccelStepper stepper1(HALF4WIRE, motorPin1, motorPin3, motorPin2, motorPin4);
AccelStepper stepper2(HALF4WIRE, motorPin5, motorPin7, motorPin6, motorPin8);
AccelStepper stepper3(HALF4WIRE, motorPin9, motorPin11, motorPin10, motorPin12);

long m1, m2, m3; // moveTo target positions of 3 motors
long c1, c2, c3; // current positions of 3 motors
bool motorRunning;

// Character to end command/response
int LF_CHAR = 10;

void setup ( ) {
  // Starting the serial communication at 9600 baud rate
  Serial.begin(9600); 
  m1 = m2 = m3 = 0;
  c1 = c2 = c3 = 0;
  motorRunning = false;
} 

void configMotors() {
  stepper1.moveTo(-m1);
  stepper2.moveTo(-m2); 
  stepper3.moveTo(-m3);  

  // speed is linear when the value is below 1000. 
  int d1 = m1 > c1 ? m1 - c1 : c1 - m1;
  int d2 = m2 > c2 ? m2 - c2 : c2 - m2;
  int d3 = m3 > c3 ? m3 - c3 : c3 - m3;
  int dmax = d1 > d2 ? d1 : d2;
  if (d3 > dmax)
    dmax = d3; 
  float s1 = 9000.0 * d1 / dmax;
  float s2 = 9000.0 * d2 / dmax;
  float s3 = 9000.0 * d3 / dmax;
  stepper1.setMaxSpeed(s1);
  stepper2.setMaxSpeed(s2);
  stepper3.setMaxSpeed(s3);
  
  stepper1.setAcceleration(500.0);
  stepper2.setAcceleration(500.0);
  stepper3.setAcceleration(500.0);
}

// Return true if at least one motor is still running
bool runMotors() {
  bool f1 = stepper1.run();
  bool f2 = stepper2.run();
  bool f3 = stepper3.run();
  c1 = stepper1.currentPosition();
  c2 = stepper2.currentPosition();
  c3 = stepper3.currentPosition();
  if (c1 == m1 && c2 == m2 && c3 == m3)
    return false;
  if (!(f1 || f2 || f3))
    return false;
  return true;
}

void sendResponse() {
  byte resp[13];
  long c;
  resp[0] = 'c';
  c = -c1;
  resp[1] = byte(((c >> 12) & 0xf) + 48);
  resp[2] = byte(((c >> 8) & 0xf) + 48);
  resp[3] = byte(((c >> 4) & 0xf) + 48);
  resp[4] = byte((c & 0xf) + 48); 
  c = -c2;
  resp[5] = byte(((c >> 12) & 0xf) + 48);
  resp[6] = byte(((c >> 8) & 0xf) + 48);
  resp[7] = byte(((c >> 4) & 0xf) + 48);
  resp[8] = byte((c & 0xf) + 48); 
  c = -c3;
  resp[9] = byte(((c >> 12) & 0xf) + 48);
  resp[10] = byte(((c >> 8) & 0xf) + 48);
  resp[11] = byte(((c >> 4) & 0xf) + 48);
  resp[12] = byte((c & 0xf) + 48); 
  Serial.write(resp, 13);

  // debug
  //Serial.write('m');
  //Serial.print(m1, DEC);
  //Serial.print(m2, DEC);
  //Serial.print(m3, DEC);

  // append LF and flush
  Serial.write(LF_CHAR);
  Serial.flush();
}

// Block to receive command. Set m1, m2, m3 and return true if received a valid command.
// Respond error message and return false if received a bad command.
bool receiveCommand() {
  int len = 16;
  byte cmd[len];
  // block waiting to receive command, which ends with LF
  int i = 0;
  int b = 0;
  while (true) {
    while(Serial.available() == 0) {
      delay(1);
    }
    b = Serial.read();
    if (b == LF_CHAR)
      break;
    cmd[i] = b;
    ++i;
    if (i == len)
      i = 0;
  }
  
  // check if the command is valid
  if (i != 13 || cmd[0] != 'm') {
    Serial.write("rBad command ");
    Serial.write(cmd, i);
    Serial.write(LF_CHAR);
    Serial.flush();
    return false;
  }

  // get m1, m2, m3.
  m1 = cmd[1] - 48;
  m1 <<= 4;
  m1 += cmd[2] - 48;
  m1 <<= 4; 
  m1 += cmd[3] - 48;
  m1 <<= 4; 
  m1 += cmd[4] - 48;
  
  m2 = cmd[5] - 48;
  m2 <<= 4;
  m2 += cmd[6] - 48;
  m2 <<= 4; 
  m2 += cmd[7] - 48;
  m2 <<= 4; 
  m2 += cmd[8] - 48;  

  m3 = cmd[9] - 48;
  m3 <<= 4;
  m3 += cmd[10] - 48;
  m3 <<= 4; 
  m3 += cmd[11] - 48;
  m3 <<= 4; 
  m3 += cmd[12] - 48; 
  return true;
}

void loop ( ) { 
  if (!motorRunning) {
    bool validCmd = receiveCommand();
    if (validCmd) {
      configMotors();
      motorRunning = true;
    }  
  } else {
    bool running = runMotors();
    if (!running) {
      sendResponse();
      motorRunning = false;
    }  
  }
}

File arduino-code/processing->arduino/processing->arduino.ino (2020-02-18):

#include <AccelStepper.h>
#define HALFSTEP 8

// motor pins
#define motorPin1  2     // IN1 on the ULN2003 driver 1
#define motorPin2  3     // IN2 on the ULN2003 driver 1
#define motorPin3  4     // IN3 on the ULN2003 driver 1
#define motorPin4  5     // IN4 on the ULN2003 driver 1

#define motorPin5  6     // IN1 on the ULN2003 driver 2
#define motorPin6  7     // IN2 on the ULN2003 driver 2
#define motorPin7  8    // IN3 on the ULN2003 driver 2
#define motorPin8  9    // IN4 on the ULN2003 driver 2

#define motorPin9  10     // IN1 on the ULN2003 driver 2
#define motorPin10  11     // IN2 on the ULN2003 driver 2
#define motorPin11  12    // IN3 on the ULN2003 driver 2
#define motorPin12  13    // IN4 on the ULN2003 driver 2

// Initialize with pin sequence IN1-IN3-IN2-IN4 for using the AccelStepper with 28BYJ-48
AccelStepper stepper1(HALFSTEP, motorPin1, motorPin3, motorPin2, motorPin4);
AccelStepper stepper2(HALFSTEP, motorPin5, motorPin7, motorPin6, motorPin8);

// variables
int turnSteps = 2100; // number of steps for a 90 degree turn
int lineSteps = -6600; //number of steps to drive straight
int stepperSpeed = 1000; //speed of the stepper (steps per second)
int steps1 = 0; // keep track of the step count for motor 1
int steps2 = 0; // keep track of the step count for motor 2

boolean turn1 = false; //keep track if we are turning or going straight next
boolean turn2 = false; //keep track if we are turning or going straight next

void setup() {
  // put your setup code here, to run once:

  Serial.begin(9600);

  delay(3000); //some time to put the robot down after switching it on

  stepper1.setMaxSpeed(2000.0);
  stepper1.move(1);  // I found this necessary
  stepper1.setSpeed(stepperSpeed);

  stepper2.setMaxSpeed(2000.0);
  stepper2.move(-1);  // I found this necessary
  stepper2.setSpeed(stepperSpeed);

}

void loop() {
  // put your main code here, to run repeatedly:
//  if (val < 10)
//    Serial.println(val, DEC);
//  val++;
//  
//  if (Serial.available()) {
//    //val = Serial.read();
//    Serial.print("I received: ");
//    Serial.println(val, DEC);
//  }
//  
////  if (val == '1') {
////    moveMotor();
////  }
////  delay(10);
}

void moveMotor() {
  if (steps1 == 0) {
    int target = 0;
    if (turn1 == true) {
      target = turnSteps;
    }

    else {
      target = lineSteps;
    }

    stepper1.move(target);
    stepper1.setSpeed(stepperSpeed);
    turn1 = !turn1;
  }

  if (steps2 == 0) {
    int target = 0;
    if (turn2 == true) {
      target = turnSteps;
    }

    else {
      target = -lineSteps;
    }

    stepper2.move(target);
    stepper2.setSpeed(stepperSpeed);
    turn2 = !turn2;
  }

  steps1 = stepper1.distanceToGo();
  steps2 = stepper2.distanceToGo();

  stepper1.runSpeedToPosition();
  stepper2.runSpeedToPosition();
}

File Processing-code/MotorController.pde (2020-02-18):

class MotorController {
  PVector mouseXY; // x,y at (0,0). z is physical height in millimeter
  PVector vp1, vp2, vp3;  // x,y on unit circle in virtual coordinate system
  PVector p1, p2, p3; // x,y in physical coordinate system
  int mstep1, mstep2, mstep3;  // motor step to move to
  int cstep1, cstep2, cstep3;  // current motor step, from last reponse from arduino


  // The min angle between normal and z-axis, i.e., the max slope of the plane
  float MIN_ANGLE_TO_Z_AXIS = PI / 6;
  // The physical distance in unit of millimeter for 1 unit on the XY plane.
  // p1, p2, p3 are on the unit circle in the virtual coordinate system.
  float XY_SCALE_FACTOR = 12;
  // The physical distance in unit of millimeters for 1 unit on the Z-axis.
  // The input height at mouseXY ranges in [0,1] in the virtual coordinate system.
  float Z_SCALE_FACTOR = 40;
  // The max z value at p1, p2, p3 in unit of millimeters
  float MAX_HEIGHT = 40;
  // The distance in unit of millimeter per motor step
  float DISTANCE_PER_MOTOR_STEP = 40.0/4096;

  // The mouseXY is at x=0, y=0
  // The three points' X and Y are relative to mouseXY and are on the unit circle.
  MotorController() {
    this.mouseXY = new PVector(0, 0);
    this.vp1 = new PVector(0, 1);
    this.vp2 = new PVector(-0.866, -0.5);
    this.vp3 = new PVector(0.866, -0.5);  
    this.p1 = new PVector(0, 1 * XY_SCALE_FACTOR);
    this.p2 = new PVector(-0.866 * XY_SCALE_FACTOR, -0.5 * XY_SCALE_FACTOR);
    this.p3 = new PVector(0.866 * XY_SCALE_FACTOR, -0.5 * XY_SCALE_FACTOR);
    this.cstep1 = 0;
    this.cstep2 = 0;
    this.cstep3 = 0;
  }

  // The input height at mouseXY ranges in [0,1]. 
  // Limit the angle between the normal vector and z-axis to 45 degrees.
  // Calculate the height for the three motors based on the height at mouseXY and normal vector. 
  // Drive motors via Arduino.
  void moveMotor(float h, PVector normal) {
    PVector ln = limitSlope(normal);
    this.mouseXY.z = h * Z_SCALE_FACTOR;
    setZForXYonPlane(ln, this.p1);
    setZForXYonPlane(ln, this.p2);
    setZForXYonPlane(ln, this.p3);
    
    limitHeights();
    
    this.vp1.z = this.p1.z / Z_SCALE_FACTOR;
    this.vp2.z = this.p2.z / Z_SCALE_FACTOR;
    this.vp3.z = this.p3.z / Z_SCALE_FACTOR;
    this.mstep1 = heightToMotorSteps(this.p1.z);
    this.mstep2 = heightToMotorSteps(this.p2.z);
    this.mstep3 = heightToMotorSteps(this.p3.z);
    if (DEBUG_HAS_ARDUINO)
      driveArduino();
    if (DEBUG_PRINT_MOTOR_HEIGHTS)
      println("Motors mouseZ", this.mouseXY.z, "normal (", normal.x, normal.y, normal.z,
        ") virtual (", vp1.z, vp2.z, vp3.z, 
        ") physical (", p1.z, p2.z, p3.z, 
        ") moveTo (", mstep1, mstep2, mstep3, 
        ") curPos (", cstep1, cstep2, cstep3, ")");
  }

  // If the normal vector is >45 degrees from the z-axis (i.e., the slope >45 degree), 
  // limit it to 45 degrees. Otherwise returns the input normal vector.
  PVector limitSlope(final PVector normal) {
    PVector v = new PVector(0, 0, 1);
    float a = PVector.angleBetween(v, normal);
    if (a <= MIN_ANGLE_TO_Z_AXIS)
      return normal;
    float k = sin(MIN_ANGLE_TO_Z_AXIS) / sin(a);
    v.x = normal.x * k;
    v.y = normal.y * k;
    v.z = normal.z * cos(MIN_ANGLE_TO_Z_AXIS) / cos(a);
    return v;
  }

  // Calculate the z value for xy on the plane defined by mouseXY and normal.
  void setZForXYonPlane(final PVector normal, PVector xy) {
    PVector directionVector = PVector.sub(xy, this.mouseXY); 
    float sum = directionVector.x * normal.x + directionVector.y * normal.y;
    directionVector.z = -(sum)/normal.z;
    xy.z = directionVector.z + this.mouseXY.z;
  }

  // Limit z-values of p1, p2, p3 to be between 0 and MAX_HEIGHT
  void limitHeights() {
    // Limit upper bound of z-value by MAX_HEIGHT
    float maxZ = (this.p1.z > this.p2.z ? this.p1.z : this.p2.z);
    maxZ = (maxZ > this.p3.z ? maxZ : this.p3.z);
    float delta = maxZ - MAX_HEIGHT; 
    if (delta > 0) {
      this.p1.z -= delta;
      this.p2.z -= delta;
      this.p3.z -= delta;
      return;
    }
    // Limit lower bound of z-value by 0.
    // The XY and Z scale factor guarantees that if a motor height >MAX_HEIGHT,
    // there cannot be another motor height <0.
    float minZ = (this.p1.z < this.p2.z ? this.p1.z : this.p2.z);
    minZ = (minZ < this.p3.z ? minZ : this.p3.z);
    if (minZ < 0) {
      this.p1.z -= minZ;
      this.p2.z -= minZ;
      this.p3.z -= minZ;
    }
  }

  // Convert the height at p1, p2, p3 in unit of millimeters to motor steps
  int heightToMotorSteps(float h) {
    return int(h / DISTANCE_PER_MOTOR_STEP);
  }

  // Send signal to arduino to drive motors. Arduino should respond with the motor steps after moving.
  void driveArduino() {
    sendCommand(this.mstep1, this.mstep2, this.mstep3);
  }

  // Command and response are printable ASCII bytes ended with LF.
  void sendCommand(int m1, int m2, int m3) {
    int LF= 10;
    int N = 64;
    byte[] response = new byte[N];
    int i = 0;

    // It is possible that the Serial buffer has part of response from the previous command.
    // Clear out the buffer.
    while (arduinoPort.available() > 0) {
      int b = arduinoPort.read();
      response[i % N] = (byte)b;
      ++i;
    }
    if (i > 0) {
      String respStr = new String(response, 0, i % N);
      println("WARN: Serial buffer has", i, "bytes from previous command", respStr);
    }

    // Send command  
    byte[] cmd = new byte[13];
    cmd[0] = 'm';
    cmd[1] = byte(((m1 >> 12) & 0xf) + 48);
    cmd[2] = byte(((m1 >> 8) & 0xf) + 48);
    cmd[3] = byte(((m1 >> 4) & 0xf) + 48);
    cmd[4] = byte((m1 & 0xf) + 48); 
    cmd[5] = byte(((m2 >> 12) & 0xf) + 48);
    cmd[6] = byte(((m2 >> 8) & 0xf) + 48);
    cmd[7] = byte(((m2 >> 4) & 0xf) + 48);
    cmd[8] = byte((m2 & 0xf) + 48); 
    cmd[9] = byte(((m3 >> 12) & 0xf) + 48);
    cmd[10] = byte(((m3 >> 8) & 0xf) + 48);
    cmd[11] = byte(((m3 >> 4) & 0xf) + 48);
    cmd[12] = byte((m3 & 0xf) + 48); 
    arduinoPort.write(cmd);
    arduinoPort.write(LF);
    String cmdStr = new String(cmd);

    // Wait for Arduino to respond, expires in 5 seconds
    i = 0;
    while (arduinoPort.available() == 0) {
      ++i;
      if (i == 10000) {
        println("ERROR no repsonse from Arduino for 10 seconds");
        return;
      }
      delay(1);
    }

    // Receive response
    i = 0;
    int b = 0;
    while (true) {
      while (arduinoPort.available() == 0) {
        delay(1);
      }
      b = arduinoPort.read();
      if (b == LF)
        break;
      response[i % N] = (byte)b;
      ++i;
    }
    String respStr = new String(response, 0, i % N);

    if (response[0] != 'c') {
      println("ERROR", respStr);
    }

    // get current position c1, c2, c3
    int c1, c2, c3;
    c1 = response[1] - 48;
    c1 <<= 4;
    c1 += response[2] - 48;
    c1 <<= 4; 
    c1 += response[3] - 48;
    c1 <<= 4; 
    c1 += response[4] - 48;
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

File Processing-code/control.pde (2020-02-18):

// Orchestrate the whole program.
// Convert between the object coordinate and screen coordinate and draw shapes.
class DirtyWork {
  PShape shape;
  ShapeGeometry2 sg;
  float scaleFactor;
  MotorController motorController;
  PVector mouseXY;
  float motorHeightFactor, normalVectorMagnitudeFactor;
  float translateX, translateY;

  void initialize(PShape shape) {
    this.mouseXY = new PVector();
    this.shape = shape;
    this.sg = new ShapeGeometry2(this.shape);
    float deltaX = this.sg.getMaxX() - this.sg.getMinX();
    float deltaY = this.sg.getMaxY() - this.sg.getMinY();
    float deltaZ = this.sg.getMaxZ() - this.sg.getMinZ();
    // Scale according to the smaller of deltaX and deltaY; 
    // reduce scaleFactor if depth exceeds deltaX/deltaY
    float ratioX = (width - 40)/ deltaX;
    float ratioY = (height - 40)/ deltaY;
    if (ratioX > ratioY) {
      this.scaleFactor = ratioY;
      if (deltaZ > deltaY)
        this.scaleFactor /= (deltaZ / deltaY) * 1.1;
    } else {
      this.scaleFactor = ratioX;
      if (deltaZ > deltaX)
        this.scaleFactor /= (deltaZ / deltaX) * 1.1;
    }
    // Screen center co-locate with object center
    this.translateX = width/2 - (this.sg.getMaxX() + this.sg.getMinX()) * this.scaleFactor/2;
    this.translateY = height/2 - (this.sg.getMaxY() + this.sg.getMinY()) * this.scaleFactor/2;
    // Normalize z-value at mouseXY between 0 and 1 to control motor.
    this.motorController = new MotorController();
    // Draw the normal vector in proportion to z-value.
    this.motorHeightFactor = 1 / (this.sg.getMaxZ() - this.sg.getMinZ());
    if (ratioX > ratioY) {
      this.normalVectorMagnitudeFactor = this.motorHeightFactor * deltaY;
    } else {
      this.normalVectorMagnitudeFactor = this.motorHeightFactor * deltaX;
    }
    this.normalVectorMagnitudeFactor /= 2;
  }

  // If mouse moves, highlight the visible facet, draw its normal vector, and
  // move the motor
  void mouseMoves() {
    this.mouseXY.x = mouseX;
    this.mouseXY.y = mouseY;
    screenToObjectCoordinate(mouseXY);
    // DEBUG check mouse XY is correct
    if (DEBUG_PRINT_MOUSE_XY)
      println("Coordinate screen", mouseX, mouseY, "object", this.mouseXY.x, this.mouseXY.y);

    PShape polygon = this.sg.getVisibleFacet(mouseXY);
    PVector normal;
    float mouseHeight;
    if (polygon == null) {
      normal = new PVector();
      normal.x = 0;
      normal.y = 0;
      normal.z = 1;
      mouseHeight = 0;
      this.motorController.moveMotor(mouseHeight, normal);
      return;
    }
    
    // highlight the visible facet 
    highlightFacet(polygon);
    
    // Get normal vector of visible polygon and set z-value at mouse XY
    // Make normal vector points toward user
    // Adjust magnitude of normal vector proportional to z-value and draw
    normal = this.sg.getNormalVectorAndSetHeight(polygon, this.mouseXY);
    if (normal.z < 0)
      normal.z *= -1;
    normal.normalize();
    PVector nvdraw = new PVector();
    nvdraw = normal.copy();
    nvdraw.mult((this.mouseXY.z - this.sg.getMinZ()) * this.normalVectorMagnitudeFactor);
    drawNormalVector(nvdraw, mouseXY);

    // Move motors. 
    // DEBUG verbose=true/false check wether motor heights are correct
    // DEBUG comment our driveArduino in moveMotor when running without Arduino
    mouseHeight = (mouseXY.z - this.sg.getMinZ()) * this.motorHeightFactor;
    this.motorController.moveMotor(mouseHeight, normal);
    drawSideView();
  }

  // Convert the provided XY screen coordinate to object coordinate in place.
  void screenToObjectCoordinate(PVector xy) {
    float oX = (xy.x - width/2) / this.scaleFactor + (this.sg.getMaxX() + this.sg.getMinX())/2;
    float oY = (xy.y - height/2) / this.scaleFactor + (this.sg.getMaxY() + this.sg.getMinY())/2;
    xy.x = oX;
    xy.y = oY;
  }

  // Draw the relief. Set all attributes here.
  void drawRelief() {
    this.shape.setFill(color(red, green, blue));
    drawWithObjectCoordinate(this.shape);
  }

  // Highlight the visibal facet. Set all attributes here.
  void highlightFacet(PShape facet) {
    //spotLight(0, 0, 0, width/2, height/2, 400, 0, 0, -1, PI/4, 2);
    facet.setFill(color(red*0.4, green*0.4, blue*0.4));
    //textureShape(facet);
    drawWithObjectCoordinate(facet);
  }

  // Draw the normal vector. Set all attributes here.
  void drawNormalVector(PVector normal, PVector pos) {
    PShape nv = createShape(LINE, pos.x, pos.y, pos.z, pos.x + normal.x, pos.y + normal.y, pos.z + normal.z);
    nv.setFill(color(255, 0, 0));
    nv.setStrokeWeight(2, 1.2);
    drawWithObjectCoordinate(nv);
  }

  // draw motor positions in screen coordinate
  void drawSideView() {
    float initialPegHeight = heightMultiplier * 5;
    float scaleFactor = heightMultiplier * 50;
    float distBetweenPegs = 15;
    float padding = 50;
    float rectWidth = 10;
    float m1 = initialPegHeight + this.motorController.getMotorVirtualHeight(1)*scaleFactor;
    float m2 = initialPegHeight + this.motorController.getMotorVirtualHeight(2)*scaleFactor;
    float m3 = initialPegHeight + this.motorController.getMotorVirtualHeight(3)*scaleFactor;
    rect(width/9, padding, rectWidth, m1);
    rect(width/9 + distBetweenPegs, padding, rectWidth, m2);
    rect(width/9 + distBetweenPegs*2, padding, rectWidth, m3);

    //float sf = 20;
    //float minZ = 1;
    //float maxZ = 2;
    //PVector p1 = this.motorController.getMotorVirtualCoordinate(1);
    //PVector p2 = this.motorController.getMotorVirtualCoordinate(2);
    //PVector p3 = this.motorController.getMotorVirtualCoordinate(3);
    //line(sf * (p1.x + 1), sf * (p1.y + 1), sf * (p2.x + 1), sf * (p2.y + 1));
    //line(sf * (p2.x + 1), sf * (p2.y + 1), sf * (p3.x + 1), sf * (p3.y + 1));
    //line(sf * (p3.x + 1), sf * (p3.y + 1), sf * (p1.x + 1), sf * (p1.y + 1));
    //float z1, z2, z3;
    //z1 = p1.z > maxZ ? maxZ : (p1.z < minZ ? minZ : p1.z);
    //z2 = p2.z > maxZ ? maxZ : (p2.z < minZ ? minZ : p2.z);
    //z3 = p3.z > maxZ ? maxZ : (p3.z < minZ ? minZ : p3.z);
    //line(sf * (p1.x + 1), sf * (p1.y + 1), sf * (p1.x + 1), sf * (p1.y + 1 + z1));
    //line(sf * (p2.x + 1), sf * (p2.y + 1), sf * (p2.x + 1), sf * (p2.y + 1 + z2));
    //line(sf * (p3.x + 1), sf * (p3.y + 1), sf * (p3.x + 1), sf * (p3.y + 1 + z3));

    //line(sf * (p1.x + 1), sf * (p1.y + 1 + z1), sf * (p2.x + 1), sf * (p2.y + 1 + z2));
    //line(sf * (p2.x + 1), sf * (p2.y + 1 + z2), sf * (p3.x + 1), sf * (p3.y + 1 + z3));
    //line(sf * (p3.x + 1), sf * (p3.y + 1 + z3), sf * (p1.x + 1), sf * (p1.y + 1 + z1));
  }

  // Draw shape whose geometry uses its own coordinates.
  void drawWithObjectCoordinate(PShape shape) {
    pushMatrix();
    translate(this.translateX, this.translateY);
    scale(scaleFactor);
    shape(shape);
    //textureShape(sg.getAllFacets());
    //shape.setFill(color(random(255), random(255), random(255) ));
    popMatrix();
  }
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

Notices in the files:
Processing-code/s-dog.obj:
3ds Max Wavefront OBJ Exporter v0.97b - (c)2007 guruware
